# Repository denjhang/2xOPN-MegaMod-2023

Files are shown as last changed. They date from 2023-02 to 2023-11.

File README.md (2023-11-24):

# 2xOPN-MegaMod 
 New version 2xOPN expansion module, adding the latest stereo selection circuit, suitable for MegaGRRL Desktop.  

# 2023.11.25
2xOPN MegaMod v0.4 and Mixer v0.2 have passed hardware testing and all functions have been verified. The old version has many problems and is not recommended.  
## 2xOPN MegaMod v0.4 includes the following features:
1. Supports playing single OPN, double OPN, single PSG, and double PSG music. Compatible with PC9801-26K, some arcade machines, ZX-Spectrum Turbo Sound FM, Atari ST, Atari STE VGM format music.Software driver support provided by natalie.  

## 2xOPN Mixer v0.2 includes the following features:  
1. A typical dual op amp driven by a single 5V (take NE5532 as an example), it works well and sounds loud.    
2. Independent volume adjustment knob. Supports adjusting the volume of OPN and SSG, as well as the overall volume of the mixer. The volume of OPLL cannot be adjusted because the volume of OPLL itself is too small. This function is completely normal, and the volumes of each channel will not interfere with each other when adjusting the volume.  
3. SSG can be configured with stereo sound. Use three three-position toggle switches to independently control the stereo channels of each SSG. This function is completely normal and will not affect the volume of OPN and OPLL.
4. SSG stereo mixing circuit. This part is based on the ZX-Spectrum's golden ratio mixing circuit, but I modified the resistor values to provide a more stereo effect.  
5. Stereo FM mixing circuit, especially used for dual OPN music.
6. Fully configurable OPN stereo, switched using a three-position switch.

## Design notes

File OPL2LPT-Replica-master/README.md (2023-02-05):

# OPL2LPT-Replica

## Introduction
**OPL2LPT-Replica** is a re-designed, open-source simplified version of OPL2LPT circuit board with fewer components under MIT license, acting as a YM3812 FM synthesizer on LPT port, and fully ***Adlib Card*** compatible.

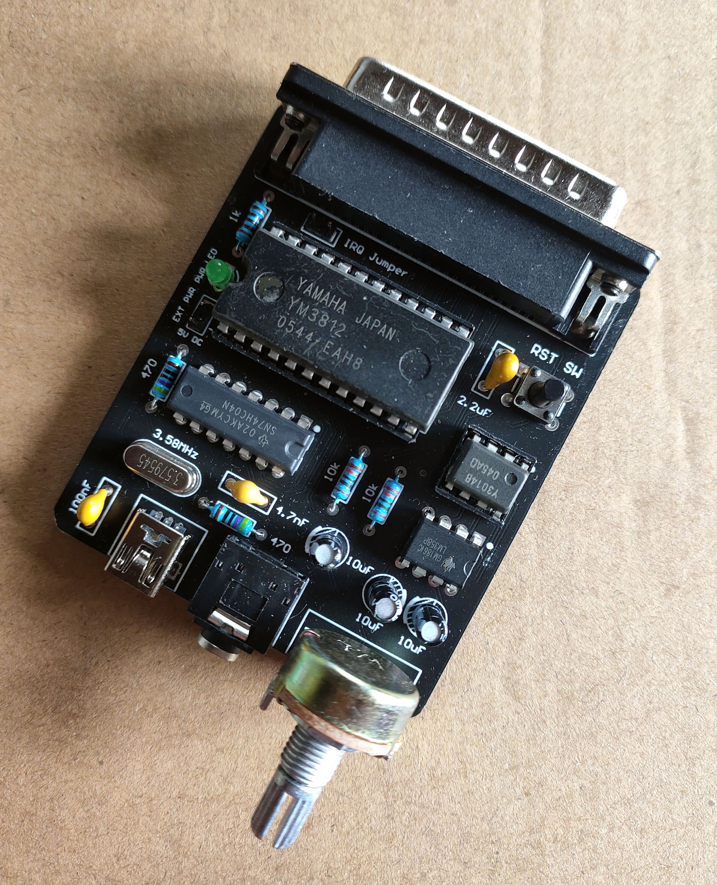
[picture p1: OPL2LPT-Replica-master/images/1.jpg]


Buy the original version of OPL2LPT and for more info: https://www.serdashop.com/OPL2LPT

## Development & Manufacture
- Please use ***Altium Designer 16*** or above to open or edit the PCB project

- Gerber files and NC drill files are already exported in `gerbers` folder, so that PCB samples can be easily manufactured

   https://www.jlc.com/ is recommended to order PCB samples in China

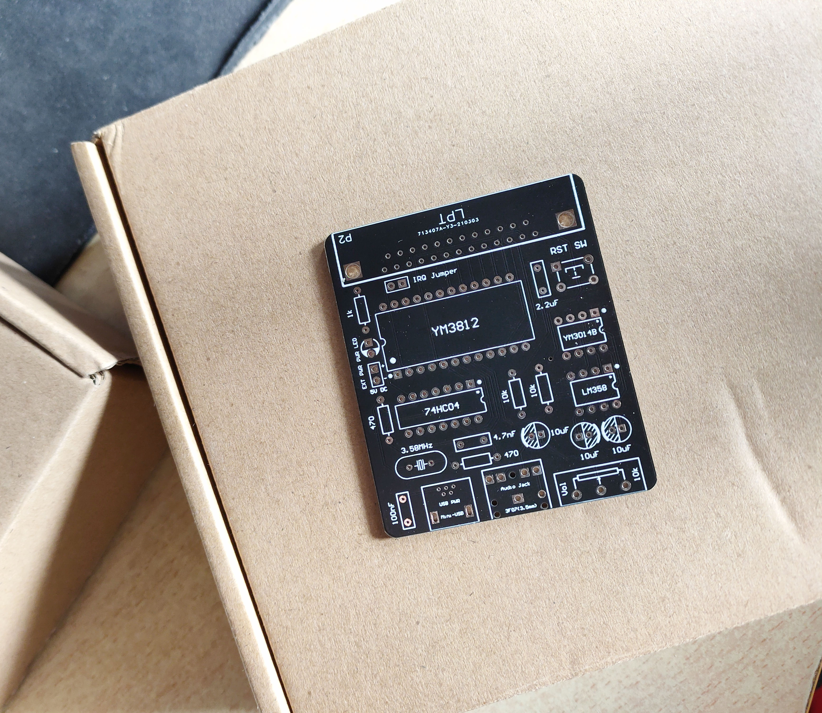
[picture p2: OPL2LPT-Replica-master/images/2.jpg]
   
## Bill of Material

| Component | Designator | Quantity | Note & Possible Sources |
| --- | --- | --- | --- |
| Leaded 100pF (101) MLCC | C1 | 1 | Mouser 594-K101J15C0GF5UH5 |
| Leaded 100nF (104) MLCC | C2 | 1 | Mouser 594-K104K15X7RF5UL2 |
| Leaded 10uF Pol. Cap. | C3, C5, C6 | 3 | Mouser 667-ECA-1EM100 |
| Leaded 2.2uF (225) MLCC | C4 | 1 | Mouser 81-RDER71H225K2M1H3A |
| Leaded 3mm Green LED | D1 | 1 | Mouser 630-HLMP-Y801-JPP00 |
| 74HC04 CMOS Inverters | IC1 | 1 | Mouser 595-CD74HC04E |
| Yamaha YM3014B DAC | IC2 | 1 | https://www.aliexpress.com/item/32611185781.html, DIP-8 socket is recommended |
| Yamaha YM3812 OPL2 | IC3 | 1 | https://www.aliexpress.com/item/32595976031.html, DIP-24 socket is recommended |
| LM358 Dual OP Amp | IC4 | 1 | Mouser 595-LM358AP |
| Leaded Mini USB Type B Connector | P1 | 1 | Mouser 571-2172034-1 |
| D-Sub 25P R/A Male Connector | P2 | 1 | Mouser 523-L717SDB25P1ACH3R |
| Header 2P 2.54mm | P3, W1 | 2 | Mouser 855-M20-9990246 |
| 3F07 3.5mm Stereo Audio Jack | P4 | 1 | https://www.aliexpress.com/i/32478957056.html |
| 1k 1/4W Resistor | R1, R2, R3 | 3 | Mouser 279-YR1B1K0CC |
| 10k WH148  Potentiometer | R4 | 1 | https://www.aliexpress.com/item/32998649900.html |
| 10k 1/4W Resistor | R5, R6 | 2 | Mouser 279-YR1B10KCC |
| TSW DIP-6\*6\*11 Key | S1 | 1 | https://www.aliexpress.com/item/32725384168.html |
| Crystal HC-49S 3.58MHz | Y1 | 1 | Mouser 449-LFXTAL032257BULK |

## Notes for Assembling & Testing
- 5V DC power is needed, either from Mini-USB port or external power pins

- Try to press **RST SW** to apply a manual reset when YM3812 behaves abnormal

- Detailed parameters for components are noted on the board's silkscreen

- Crystal must be 3.58MHz for accurate pitch of notes

- Using 74LS04 to substitute 74HC04 for the Pierce oscillator is not recommended

  **Note**: If the oscillator doesn't work, replace the two 1k ohms resistors around the 74HC04 IC with higher value resistors such as 4.7k ohms. Fine tuning for 100pF (101) MLCC capacitor around the 74HC04 may be also needed.

- Available open-source drivers for this project:
  - on MS-DOS: https://github.com/pdewacht/adlipt
    
    working fine using either method below
    
    - Using TSR  `adlipt`  for port mapping (with emm386.exe)
    - Using  `adpatch`  to patch part of DOS games
    
  - on Windows 3.1: https://github.com/andreiw/adlib21
## Update Logs
- Version 0.1(beta): First PCB for debugging
- Version 0.2(beta):
  - A smaller re-designed PCB
  - Audio quality improved
- Version 0.3(beta): Fix unconnected GND net for 3.5mm audio jack
- Version 1.0:
  - First version updated on https://github.com/
  - Fix power LED & volume control's problem
  - Use a round PCB corner for easier assembling (with a 3D-Printed case)
  - Pull-up resistors on bus are removed to improve compatibility for some old PCs
  - Use non-SMT Mini-USB port, making it easier to solder by hand
  - Add external 5V-DC power pins
- Version 1.0.1:
  - Add 3D-Printed case (with cover) and knob
  
    Thanks for **@zhblue** for your awesome *.stl models
  
  - Change directory structure for GitHub repo

- Version 1.1.0:
  - Fix clock problem caused by unsuitable resistors and capacitor for Pierce oscillator
  - Add Bill of Material and some images for this README document
  - Export PDF version for schematic and PCB documents

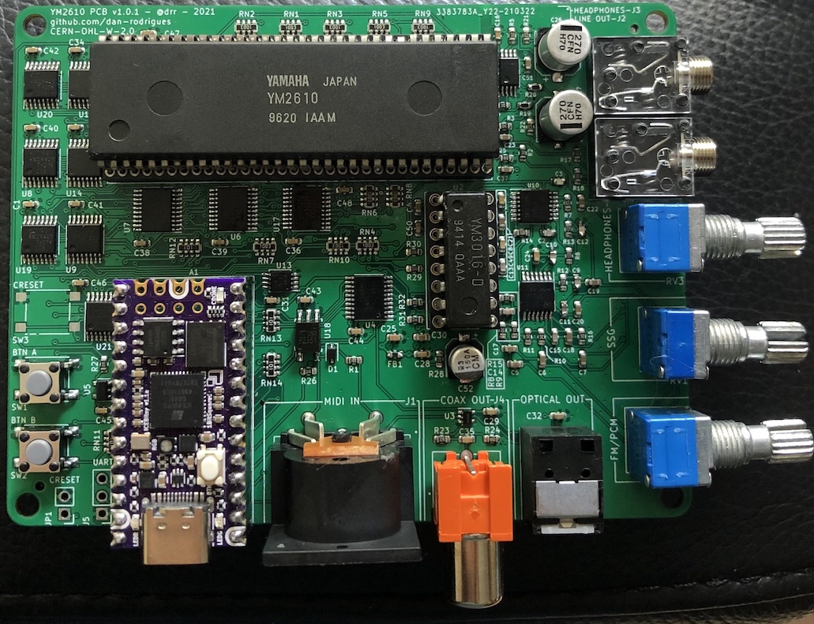
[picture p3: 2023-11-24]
参考资料/ym2610-pcb-master/ym2610-pcb-master/photo/pcb4.jpg

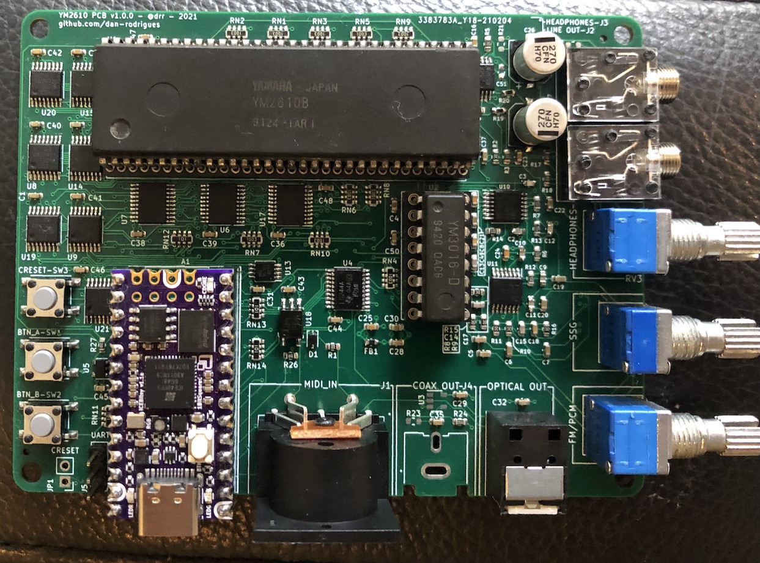
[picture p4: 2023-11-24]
参考资料/ym2610-pcb-master/ym2610-pcb-master/photo/pcb3.jpg

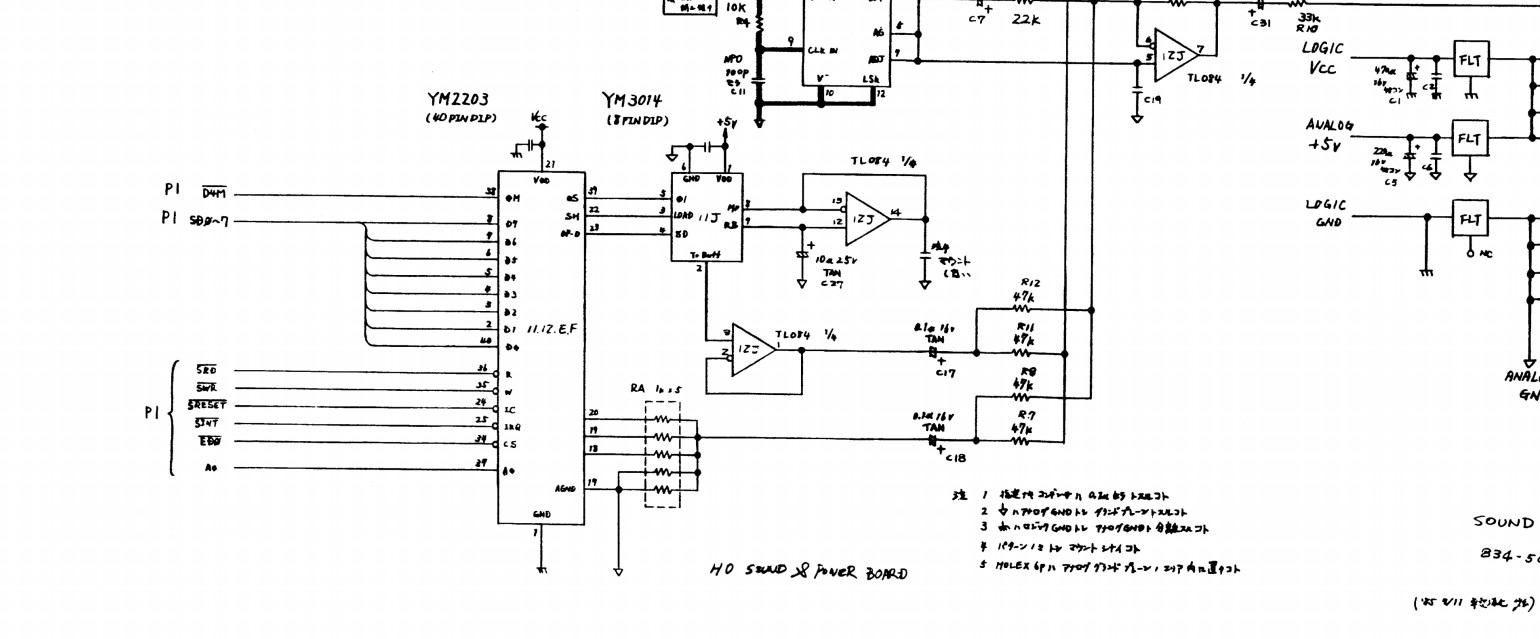
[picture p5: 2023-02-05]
截图未命名0113194031.jpeg

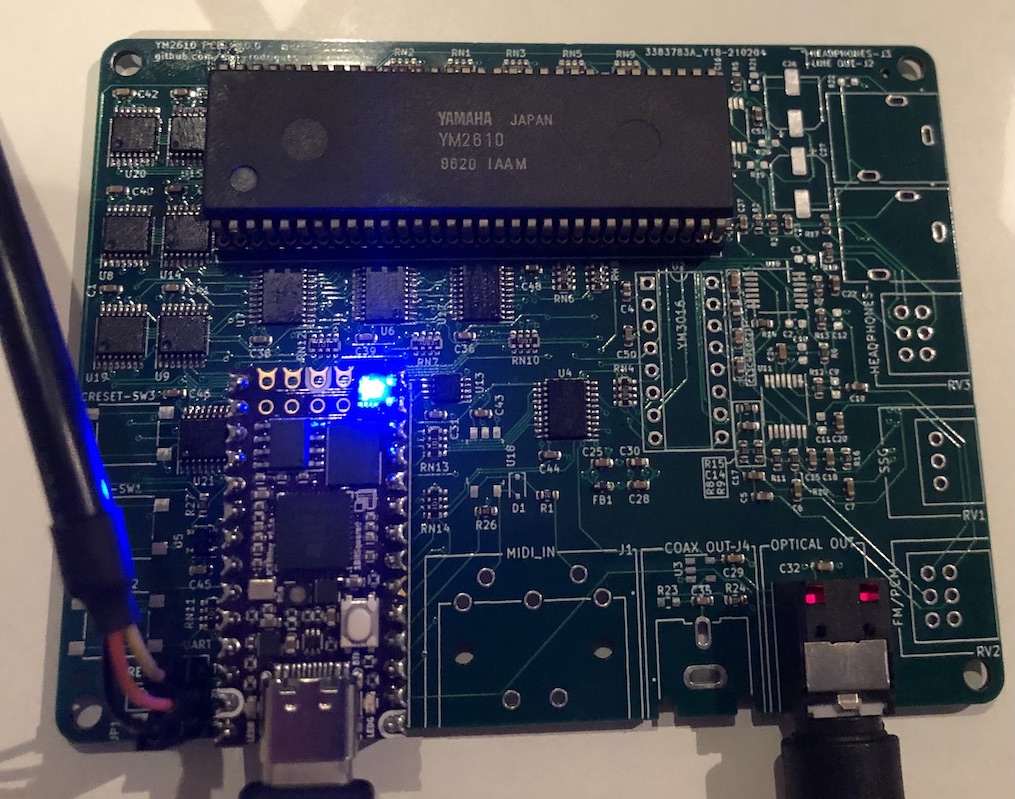
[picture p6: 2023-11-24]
参考资料/ym2610-pcb-master/ym2610-pcb-master/photo/pcb1.jpg

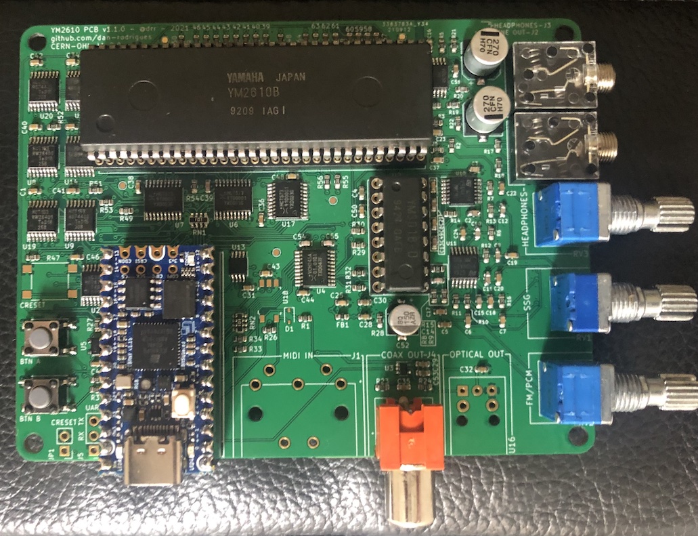
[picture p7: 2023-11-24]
参考资料/ym2610-pcb-master/ym2610-pcb-master/photo/pcb5.jpg

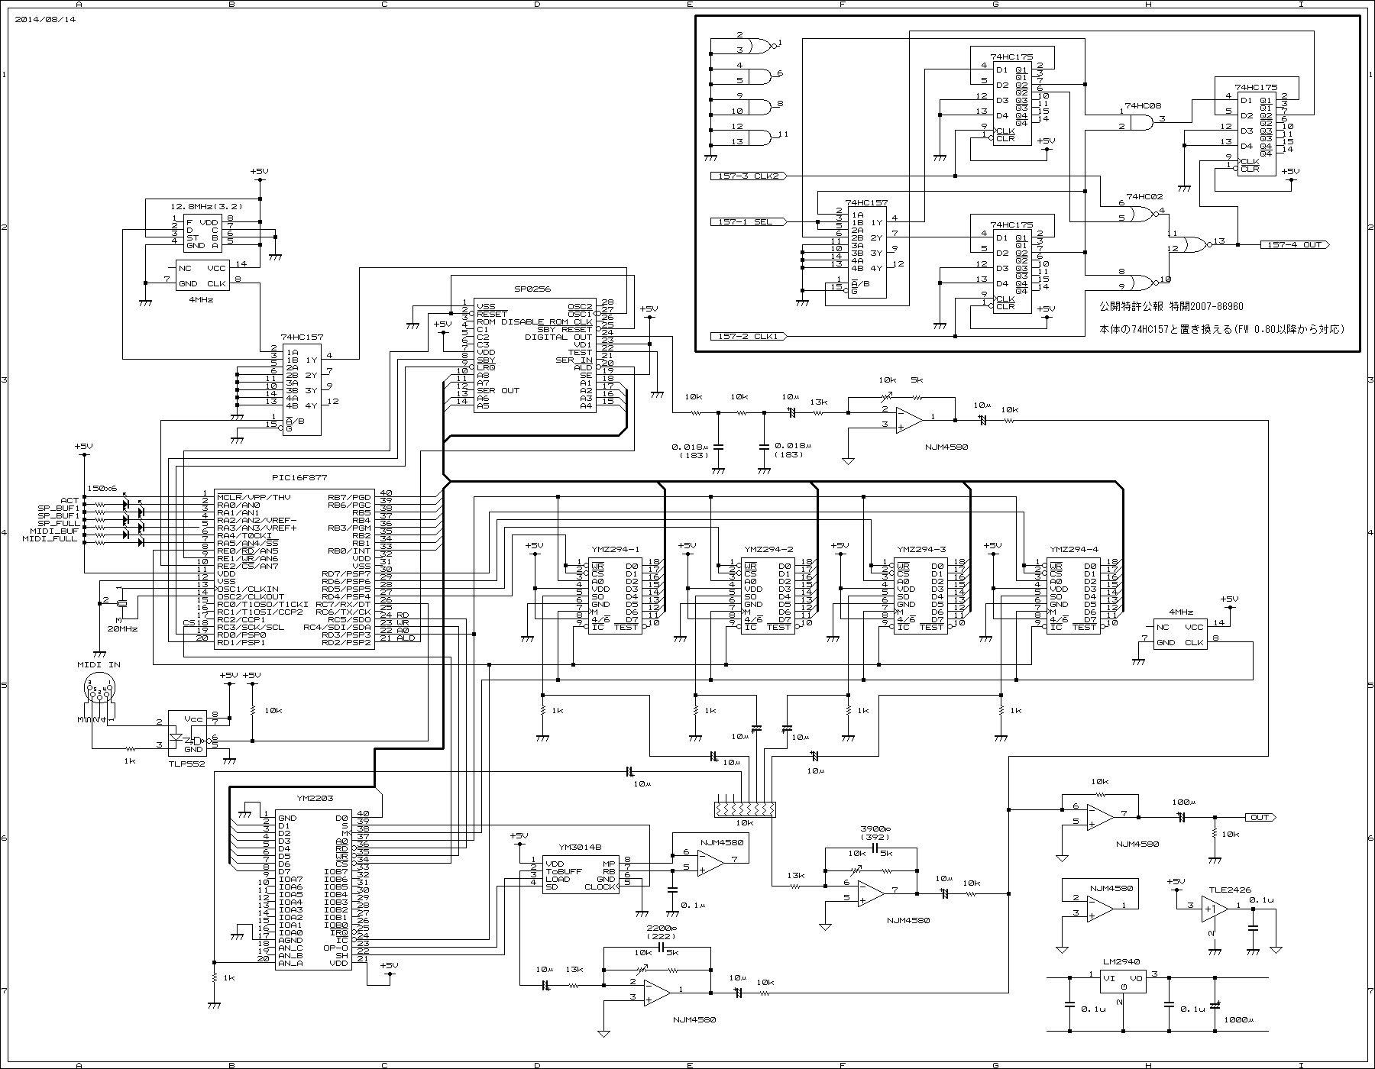
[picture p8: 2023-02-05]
schem.gif

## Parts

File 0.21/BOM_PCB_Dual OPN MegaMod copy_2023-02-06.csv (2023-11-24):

ID | Name | Designator | Footprint | Quantity | Manufacturer Part | Manufacturer | Supplier | Supplier Part | Price
1 | SS14 | D2,D1 | SMA_L4.4-W2.8-LS5.4-RD | 2 | SS14 | MDD | LCSC | C2480 | 0.0907
2 | PTC1206 0.75A/60V | FUSE1 | F1206 | 1 | PTC1206SMD1206P010TF0.1A/60V | null | LCSC | C9900017664
3 | LED0603 | LED1 | LED0603-RD | 1 | GBG-C192KRKT | GBG | LCSC | C2892154 | 0.0219
4 | LED-0603_R | LED2,LED3 | LED0603_RED | 2 | 19-217/R6C-AL1M2VY/3T | EVERLIGHT(台湾亿光) | LCSC | C72044 | 0.1041
5 | 5k | R24,R25 | R0603 | 2
6 | 3k3 | R26 | R0603 | 1
7 | NE5532-DJ | U8,U9,U10,U7 | DIP-8_L9.4-W6.4-P2.54-LS9.1-BL | 4 | NE5532P | TI | LCSC | C5326 | 3.1
8 | 10kΩ | R18,R19 | RES-ADJ-TH_RK09712200MY | 2 | RK09712200MY | ALPSALPINE(阿尔卑斯阿尔派) | LCSC | C231763 | 16.38
9 | HX SS13D07VG3-DJ | SW2,SW3,SW4,SW5,SW1,SW6,SW7,SW8 | SW-TH_SS13D07VG4 | 8 | HX SS13D07VG3 | hanxia(韩下) | LCSC | C5149830 | 0.1824
10 | YM2203C | U1,U4 | DIP40 | 2
11 | YM3014 | U3,U6 | DIP8 | 2
12 | MegaGRRL IC-DCSG | U5 | DIP-16_L20.4-W5.8-P2.54-LS7.6-BL | 1 | SN76489AN | Texas Instruments
13 | 5.8*5.8自锁开关 | S1,S2 | SW-TH_6P-L5.8-W5.8-P2.00-LS4.5-TR | 2 | Self-locking switch 5.8ZWhite and white260G | ReliaPro | LCSC | C56857 | 0.504
14 | PJ-307C | J1 | AUDIO-TH_PJ307C | 1 | PJ-307C | BOOMELE | LCSC | C16684 | 0.3127
15 | MegaGRRL IC-FM | U2 | DIP-24_L32.0-W13.8-P2.54-LS15.6-BL | 1 | YM2612 | YAMAHA |  | C707077 | 11.24
16 | 10u | C5,C6,C7,C17,C18,C13,C14,C8 | C0805 | 8
17 | 4.7u | C15,C16 | C0805 | 2
18 | 100Ω | L1 | L0603 | 1 | CBW160808U102T | FH | LCSC | C50069 | 0.0321
19 | 0.1u | C1,C2,C3,C4,C11,C12 | C0603 | 6
20 | 1n | C9,C10 | C0603 | 2
21 | 1k | R1,R8,R11,R12,R13,R14,R17,R22,R23 | R0603 | 9
22 | 470r | R2,R3,R4,R5,R6,R7 | R0603 | 6
23 | 1k6 | R9,R10,R15,R16 | R0603 | 4
24 | 10k | R20,R21 | R0603 | 2

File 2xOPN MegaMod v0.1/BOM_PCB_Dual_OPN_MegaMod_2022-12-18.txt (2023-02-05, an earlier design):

ID	Name	Designator	Footprint	Quantity	Manufacturer Part	Manufacturer	Supplier	Supplier Part	Price
"1"	"SS14"	"D1"	"SMA_L4.4-W2.8-LS5.4-RD"	"1"	"SS14"	"MDD"	"LCSC"	"C2480"	"0.0907"
"2"	"100Ω"	"L1"	"L0603"	"1"	"CBW160808U102T"	"FH"	"LCSC"	"C50069"	"0.0321"
"3"	"1k"	"R1,R5,R6,R7,R11,R12,R13,R19,R20,R26,R27"	"R0603"	"11"	""	""	""	""	""
"4"	"3.6k"	"R17,R18,R24,R25"	"R0603"	"4"	""	""	""	""	""
"5"	"10k"	"R2,R3,R4,R8,R9,R10,R16,R23"	"R0603"	"8"	""	""	""	""	""
"6"	"3.3k"	"R14,R21"	"R0603"	"2"	""	""	""	""	""
"7"	"5.6k"	"R15,R22"	"R0603"	"2"	""	""	""	""	""
"8"	"0.1u"	"C1,C2,C3,C4,C7,C10,C12,C16,C19,C22"	"C0603"	"10"	""	""	""	""	""
"9"	"4.7u"	"C6,C9,C15,C18"	"C0603"	"4"	""	""	""	""	""
"10"	"10n"	"C8,C17"	"C0603"	"2"	""	""	""	""	""
"11"	"YM3014"	"U5,U6"	"DIP8"	"2"	""	""	""	""	""
"12"	"4.7uF"	"C5,C14,C23,C24"	"CAP-TH_BD6.3-P2.50-D1.0-FD"	"4"	"电解电容25V 47uF"	"ValuePro"	"LCSC"	"C45704"	"0.1937"
"13"	"10uF"	"C11,C21"	"CAP-TH_BD4.0-P1.50-D0.8-FD"	"2"	"47uF 10V 4*5"	"ValuePro"	"LCSC"	"C43312"	"0.077"
"14"	"10uF"	"C13,C20"	"CAP-TH_BD6.3-P2.50-D1.0-FD"	"2"	"电解电容25V 47uF"	"ValuePro"	"LCSC"	"C45704"	"0.1937"
"15"	"PJ-307C"	"J1"	"AUDIO-TH_PJ307C"	"1"	"PJ-307C"	"BOOMELE"	"LCSC"	"C16684"	"0.2836"
"16"	"YM2203C"	"U4,U3"	"DIP40"	"2"	""	""	""	""	""
"17"	"SA5532AP"	"U7,U8,U9,U10"	"DIP8"	"4"	""	""	""	""	""
"18"	"Header-Male-2.54_1x3"	"H4,H6,H7,H9,H1,H2"	"HDR-TH_3P-P2.54-V-M-1"	"6"	"Header2.54mm 1*3P"	"BOOMELE"	"LCSC"	"C49257"	"0.0872"
"19"	"X6511WV-02H-C30D60"	"H3,H5,H8"	"HDR-TH_2P-P2.54-V-M"	"3"	"X6511WV-02H-C30D60"	"XKB Connectivity"	"LCSC"	"C706874"	"0.2046"
"20"	"MegaGRRL IC-DCSG"	"U1"	"DIP-16_L20.4-W5.8-P2.54-LS7.6-BL"	"1"	"SN76489AN"	"Texas Instruments"	""	""	""
"21"	"MegaGRRL IC-FM"	"U2"	"DIP-24_L32.0-W13.8-P2.54-LS15.6-BL"	"1"	"YM2612"	"YAMAHA"	""	"C707077"	"12.04"

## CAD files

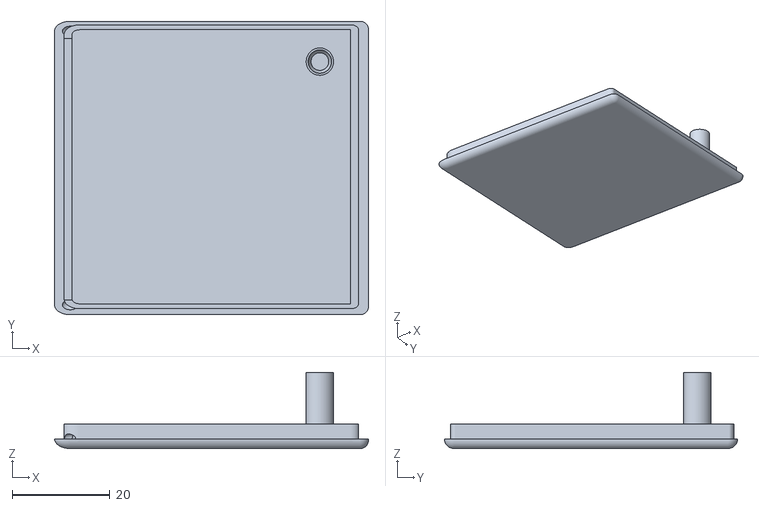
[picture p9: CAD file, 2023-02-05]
OPL2LPT-Replica-master/models/opl2cover.stl
64.2 x 60.0 x 15.6

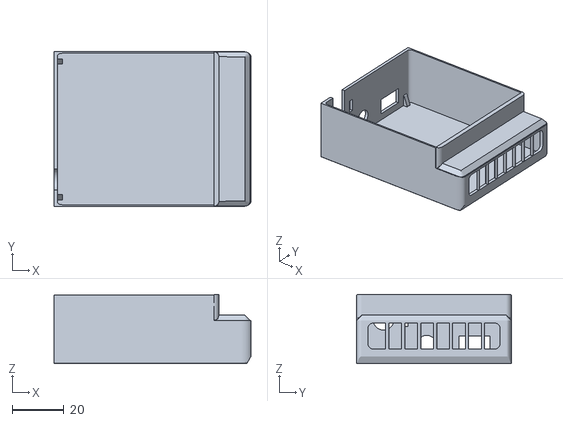
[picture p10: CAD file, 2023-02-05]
OPL2LPT-Replica-master/models/opl2box.stl
76.1 x 60.0 x 26.7

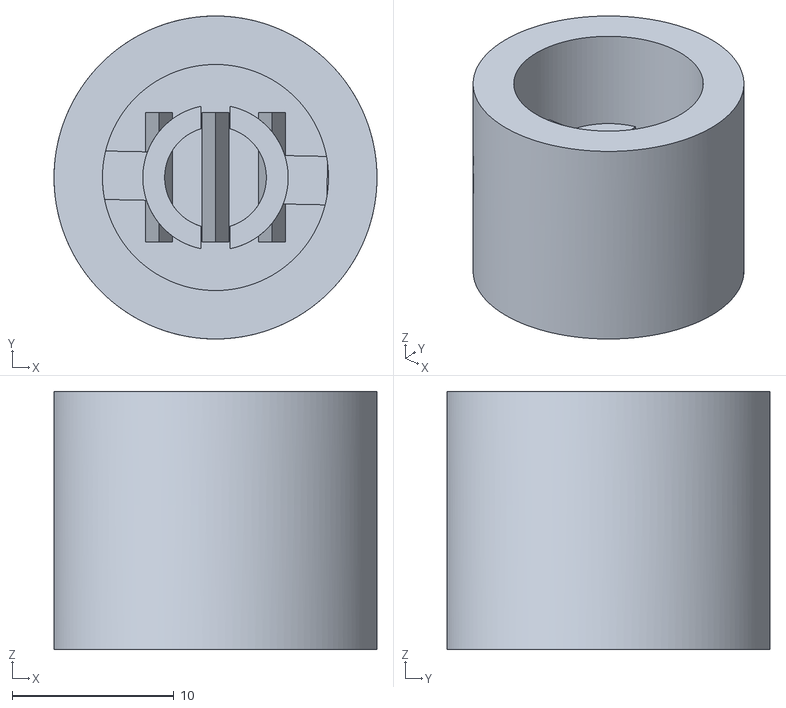
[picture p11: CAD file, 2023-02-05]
OPL2LPT-Replica-master/models/opl2knob.stl
20.0 x 20.0 x 16.0

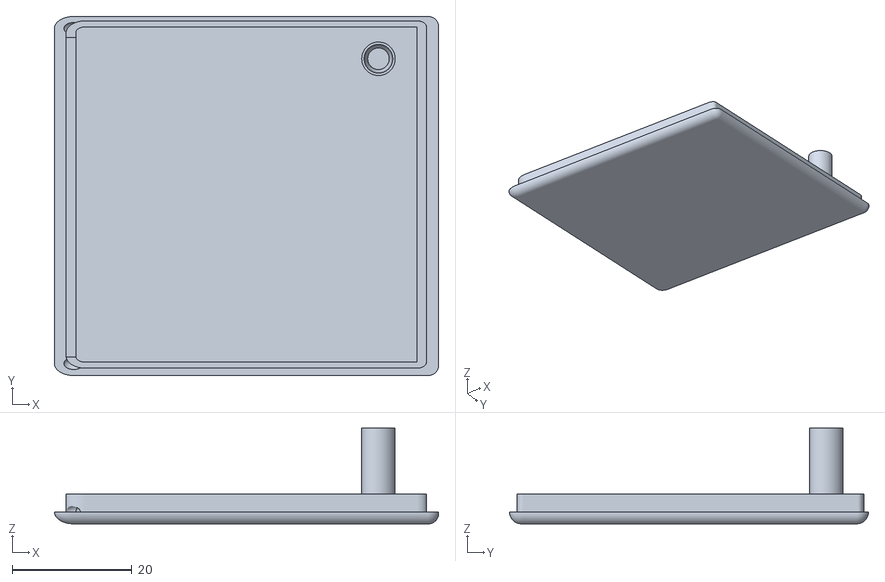
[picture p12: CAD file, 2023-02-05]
OPL2LPT-Replica-master/models/opl2coverb.stl
64.2 x 60.0 x 16.0

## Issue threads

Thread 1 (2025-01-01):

L1 / L2 are inductors or resistors?

OlivierGrimard, 2025-01-01:
Hi @denjhang,
I’m not an expert in electronics. Could you clarify if L1/L2 are inductors or resistors?
Is it possible that the value labeled as 100Ω should actually be 100nH?

Thank you

OlivierGrimard, 2025-01-04:
The answer is inductors 100nH.

Closed 2025-01-04.

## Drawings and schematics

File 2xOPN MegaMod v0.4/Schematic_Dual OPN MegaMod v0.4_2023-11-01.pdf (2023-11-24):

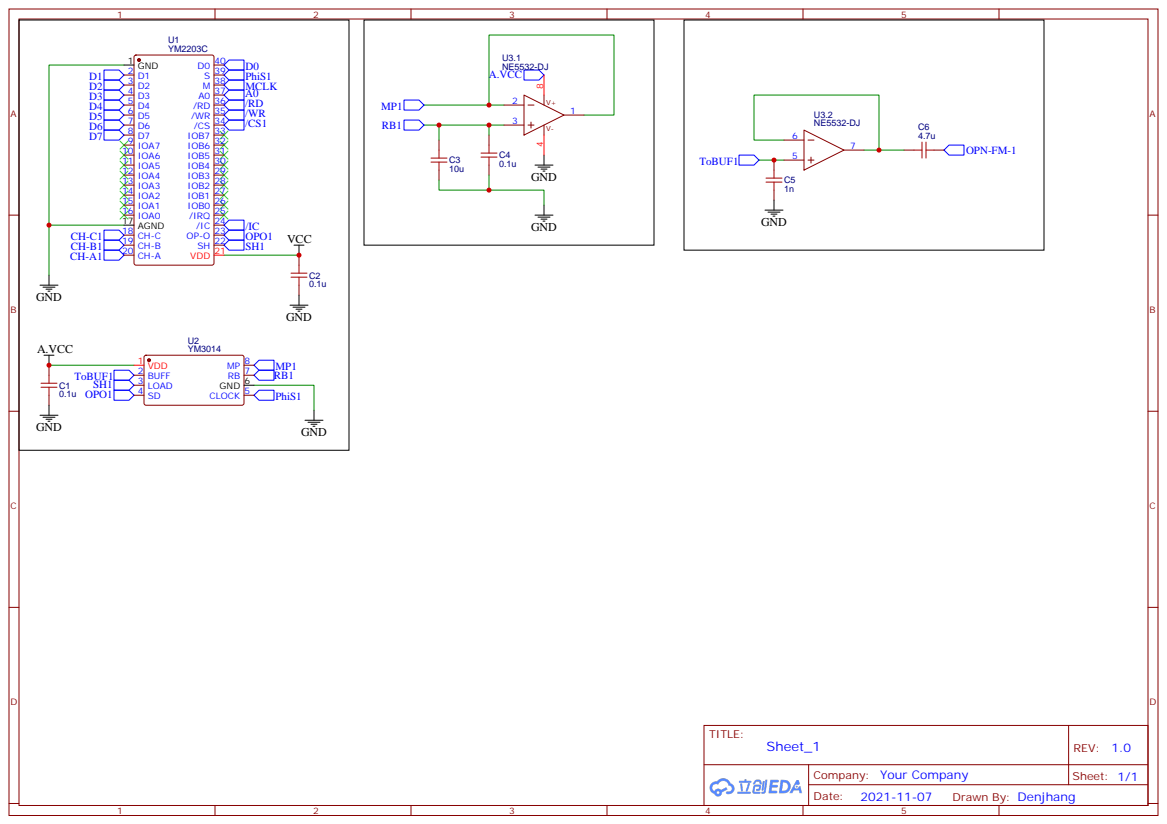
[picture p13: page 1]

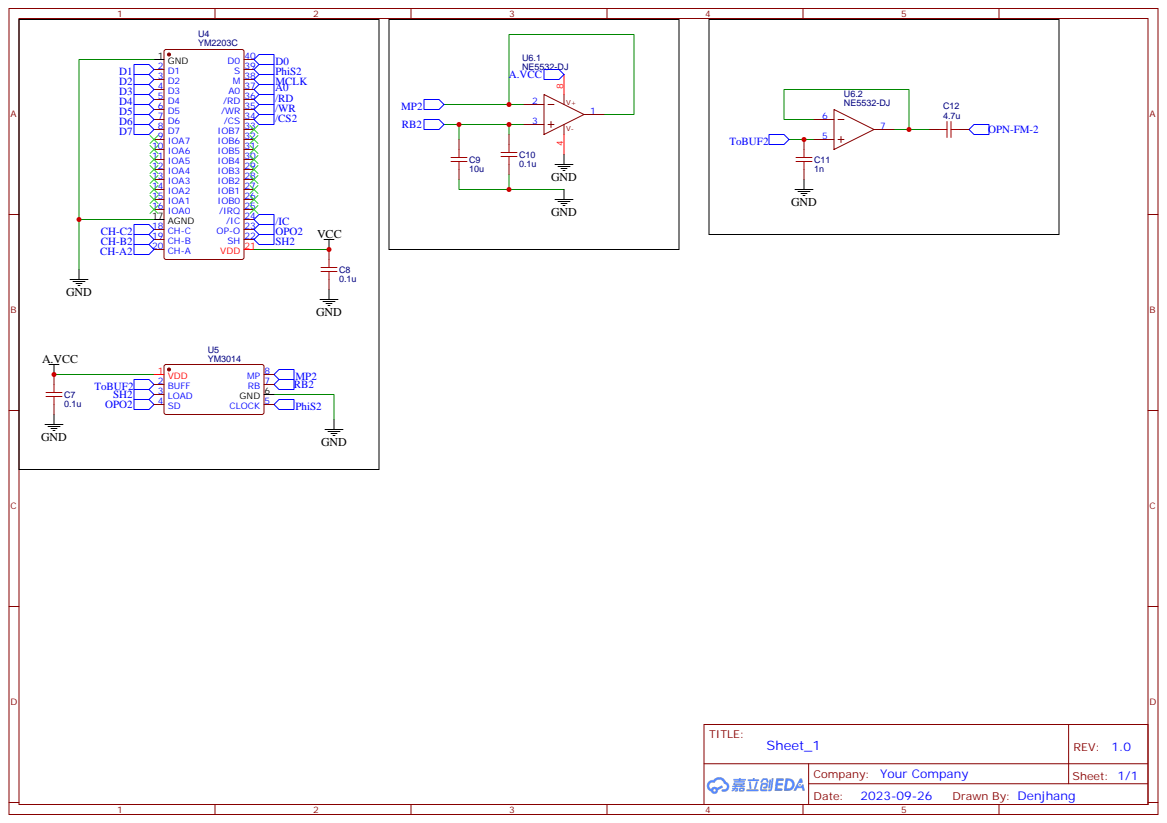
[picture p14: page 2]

## 间距53.975MM

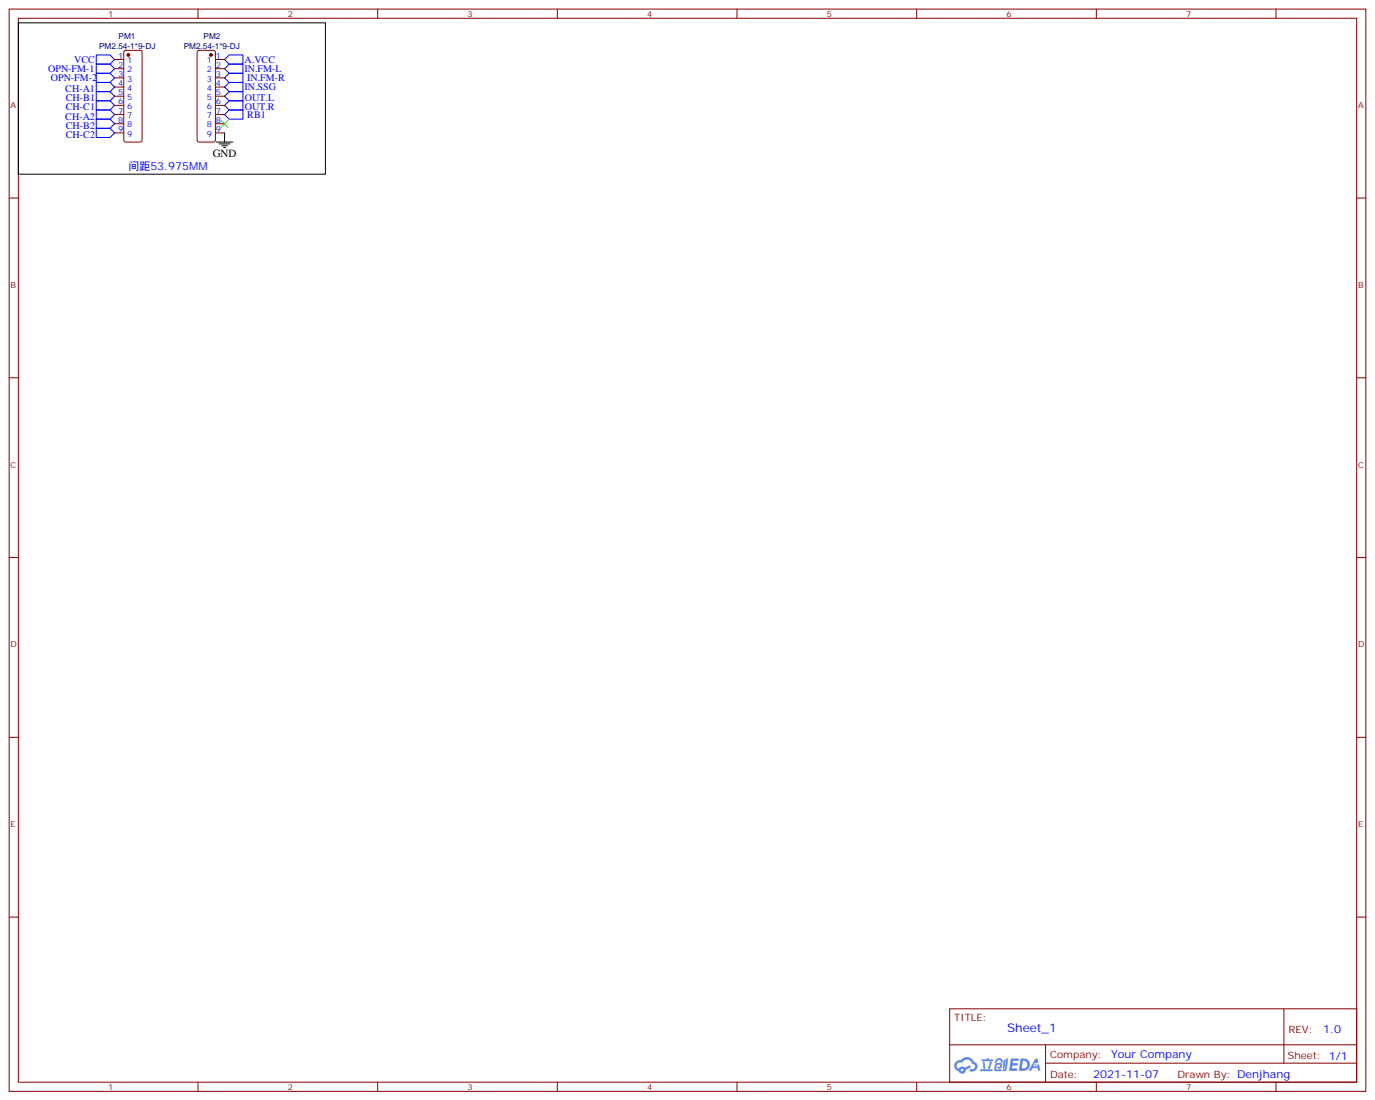
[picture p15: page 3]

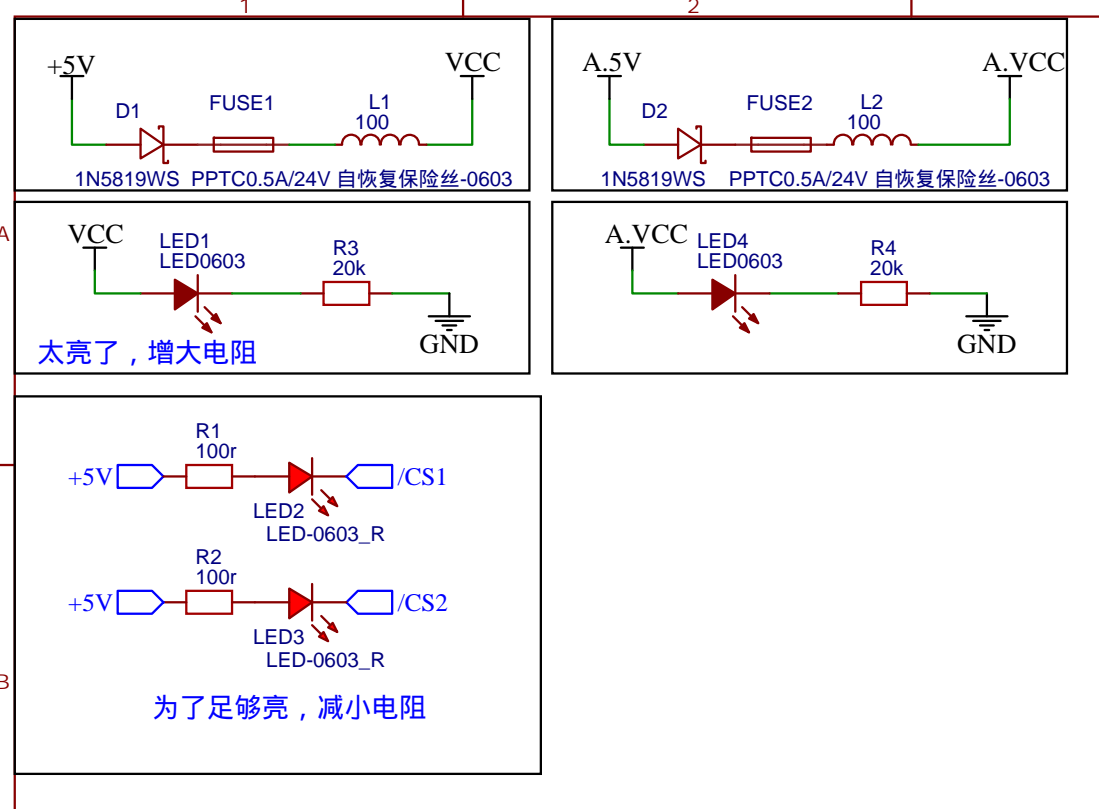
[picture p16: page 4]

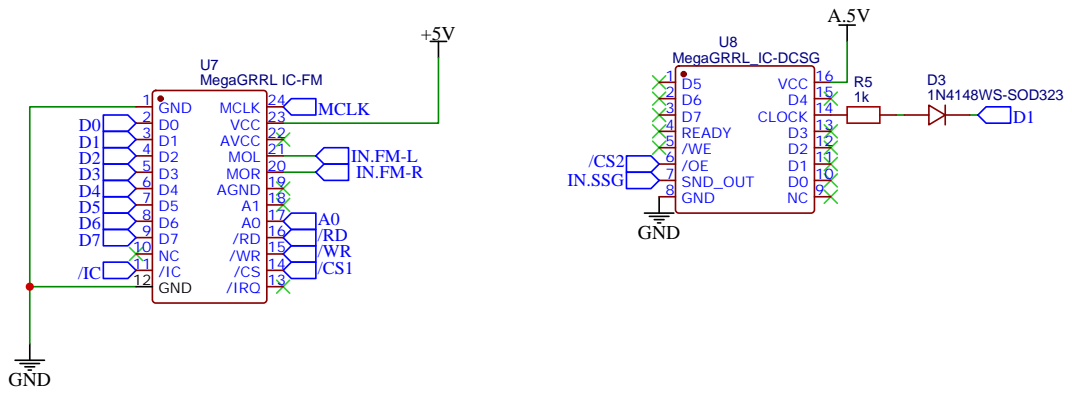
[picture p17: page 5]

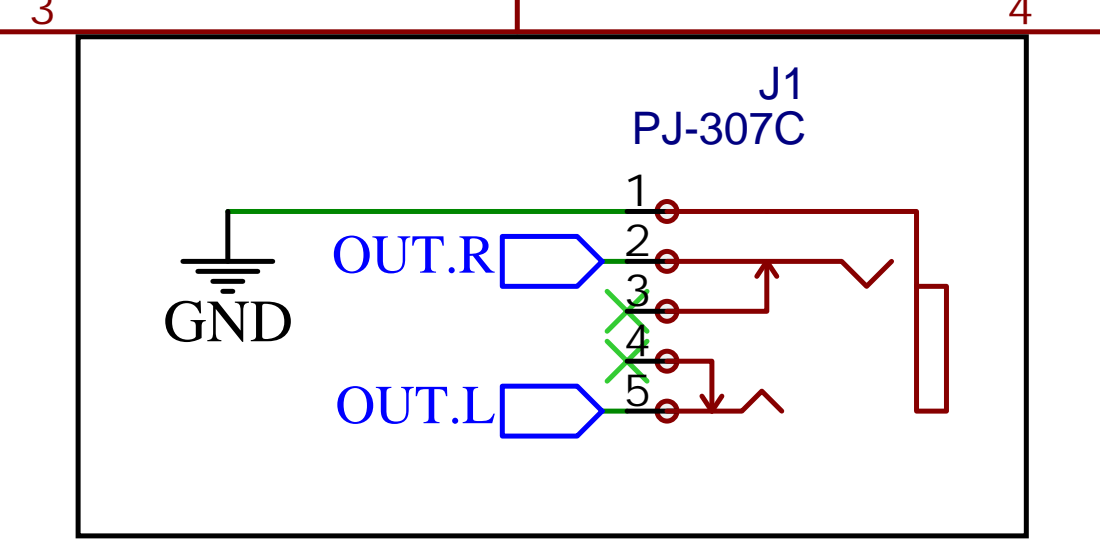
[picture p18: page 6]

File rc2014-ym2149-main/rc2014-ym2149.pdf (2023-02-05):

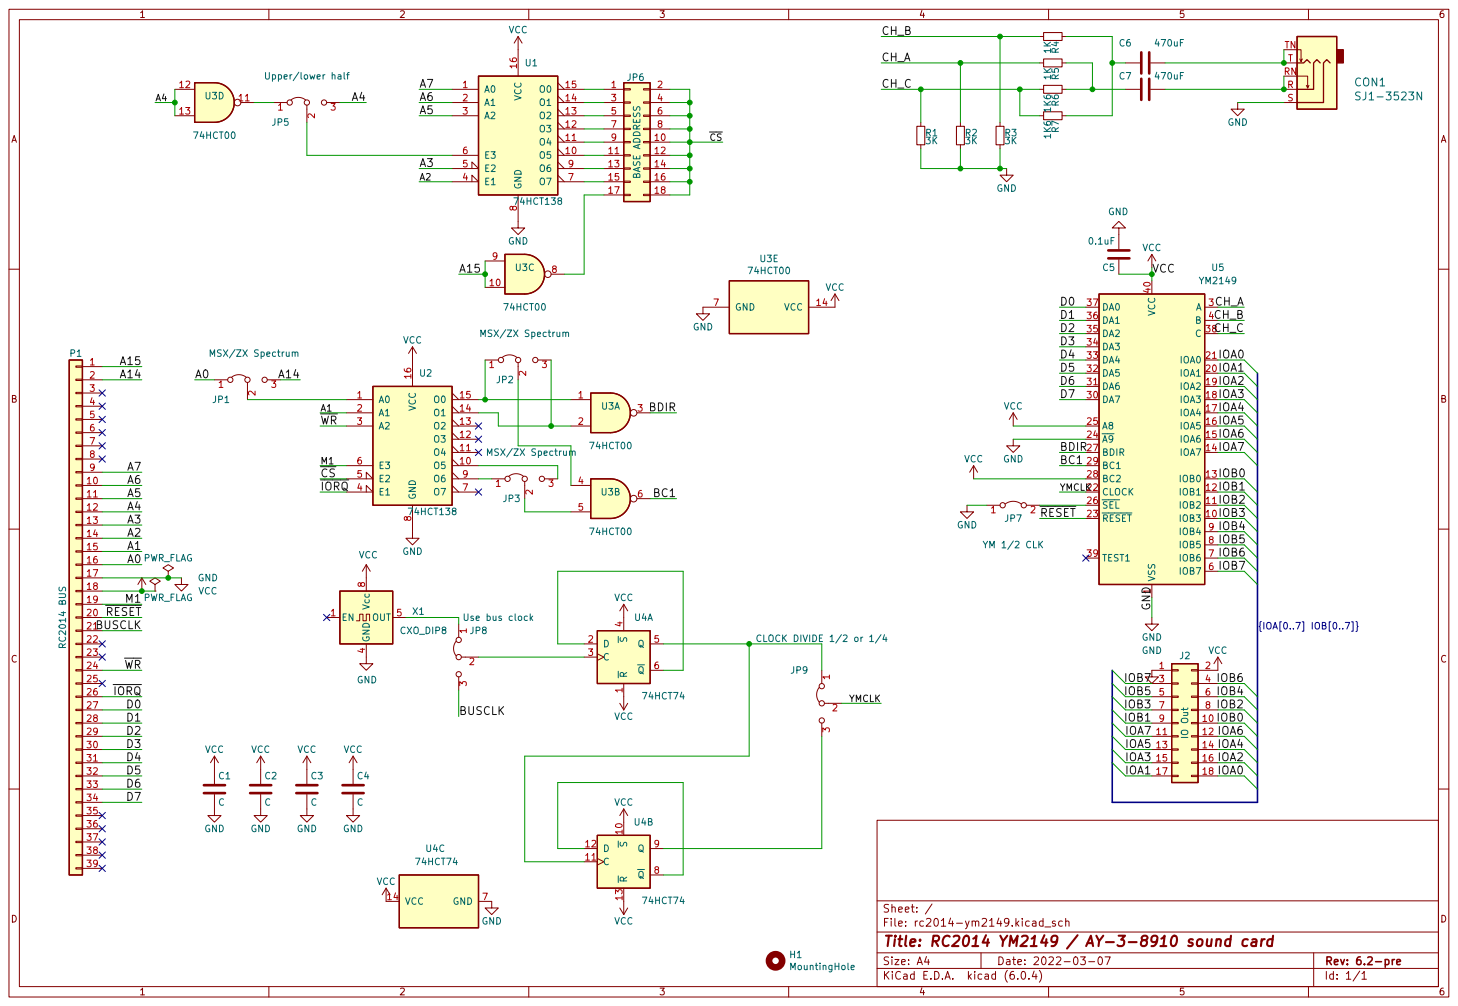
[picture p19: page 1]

13 | 14
15 | 16
17 | 18

File: rc2014-ym2149.kicad_sch Sheet: /
Id: 1/1 Title: RC2014 YM2149 / AY-3-8910 sound card

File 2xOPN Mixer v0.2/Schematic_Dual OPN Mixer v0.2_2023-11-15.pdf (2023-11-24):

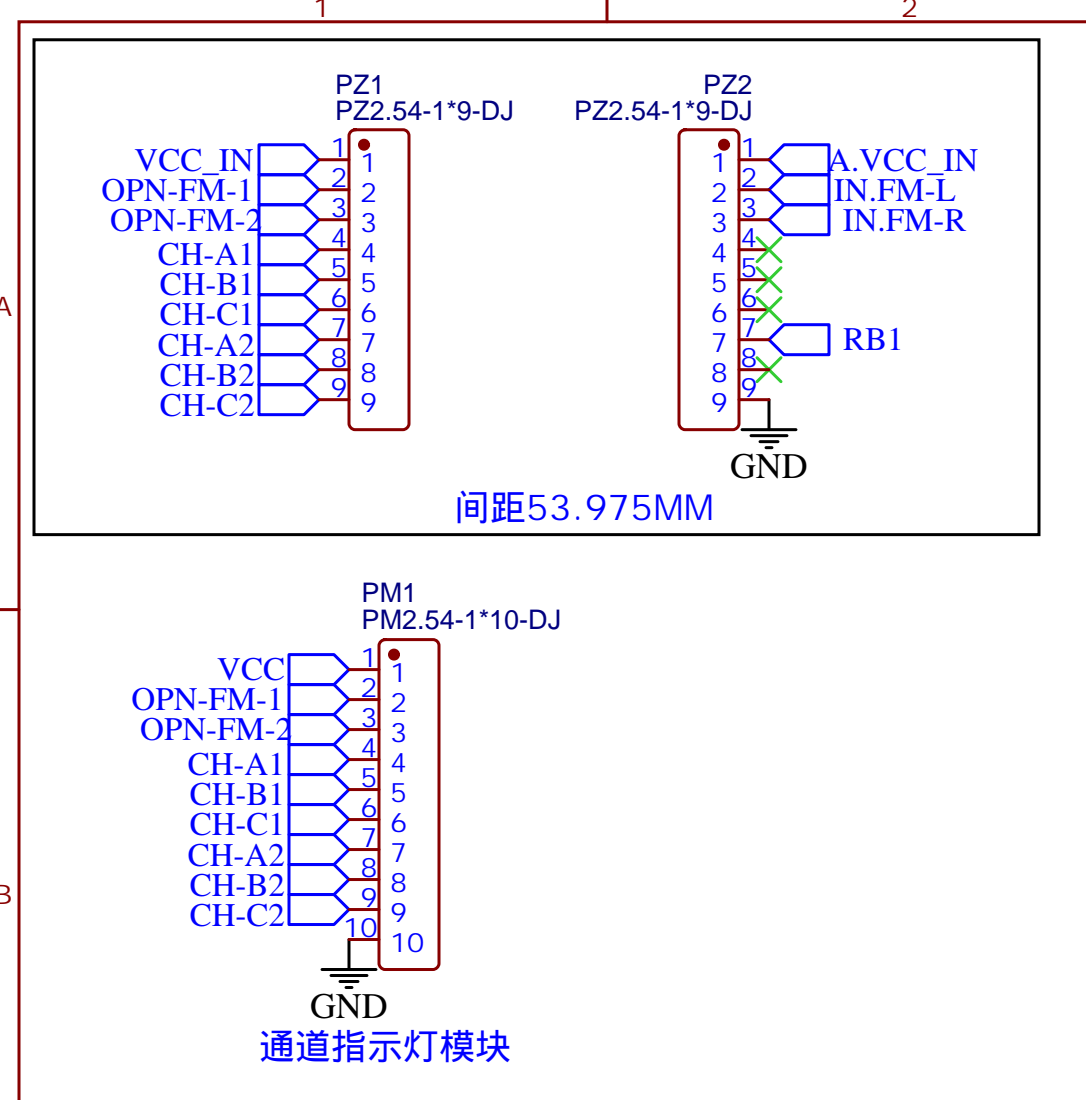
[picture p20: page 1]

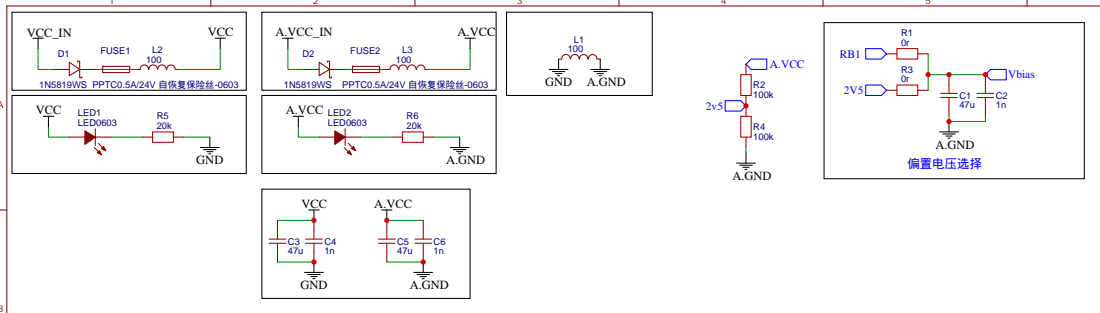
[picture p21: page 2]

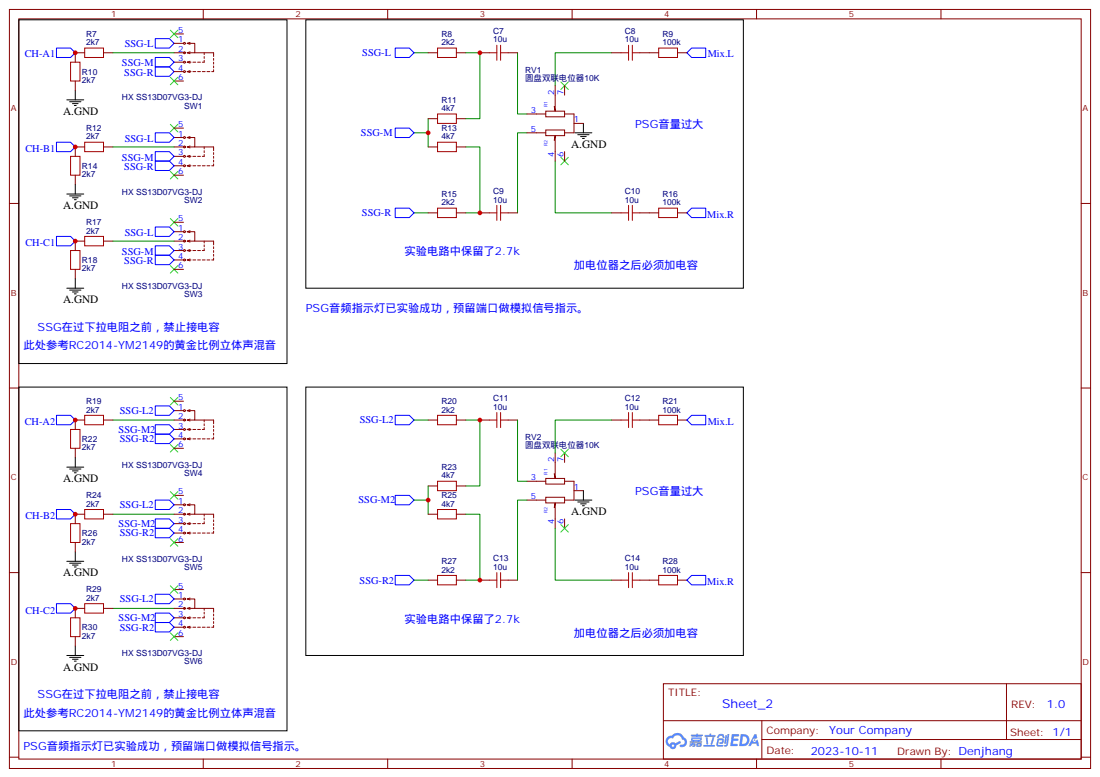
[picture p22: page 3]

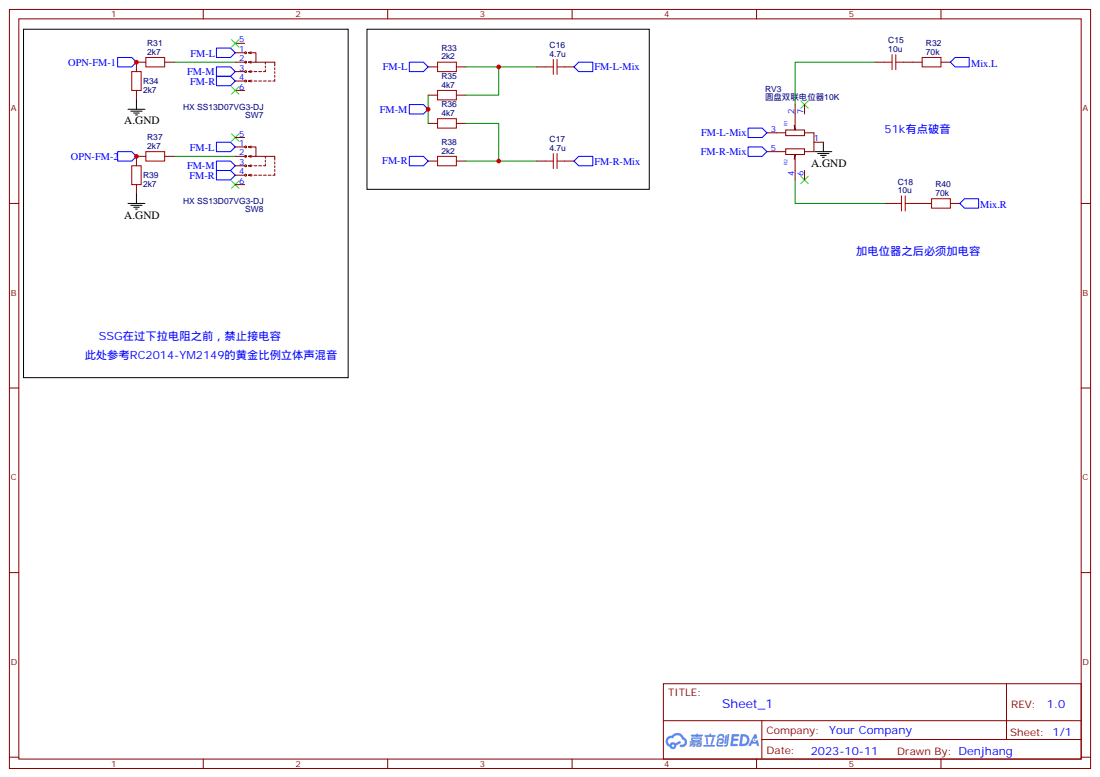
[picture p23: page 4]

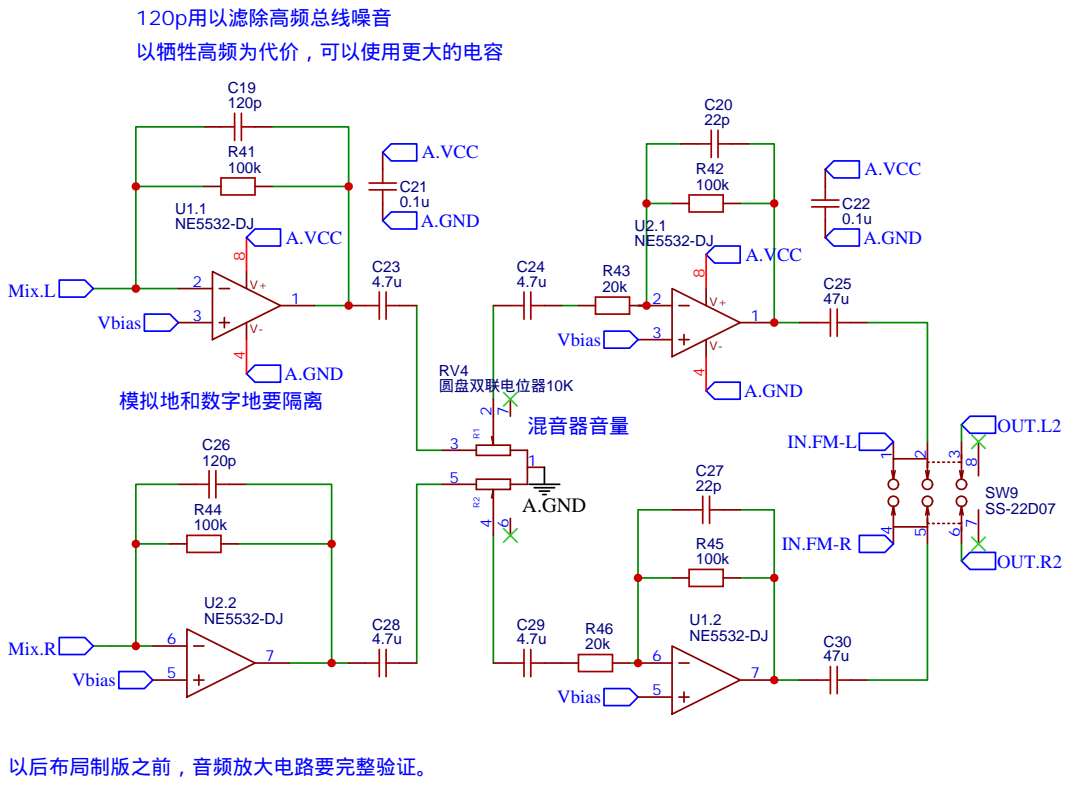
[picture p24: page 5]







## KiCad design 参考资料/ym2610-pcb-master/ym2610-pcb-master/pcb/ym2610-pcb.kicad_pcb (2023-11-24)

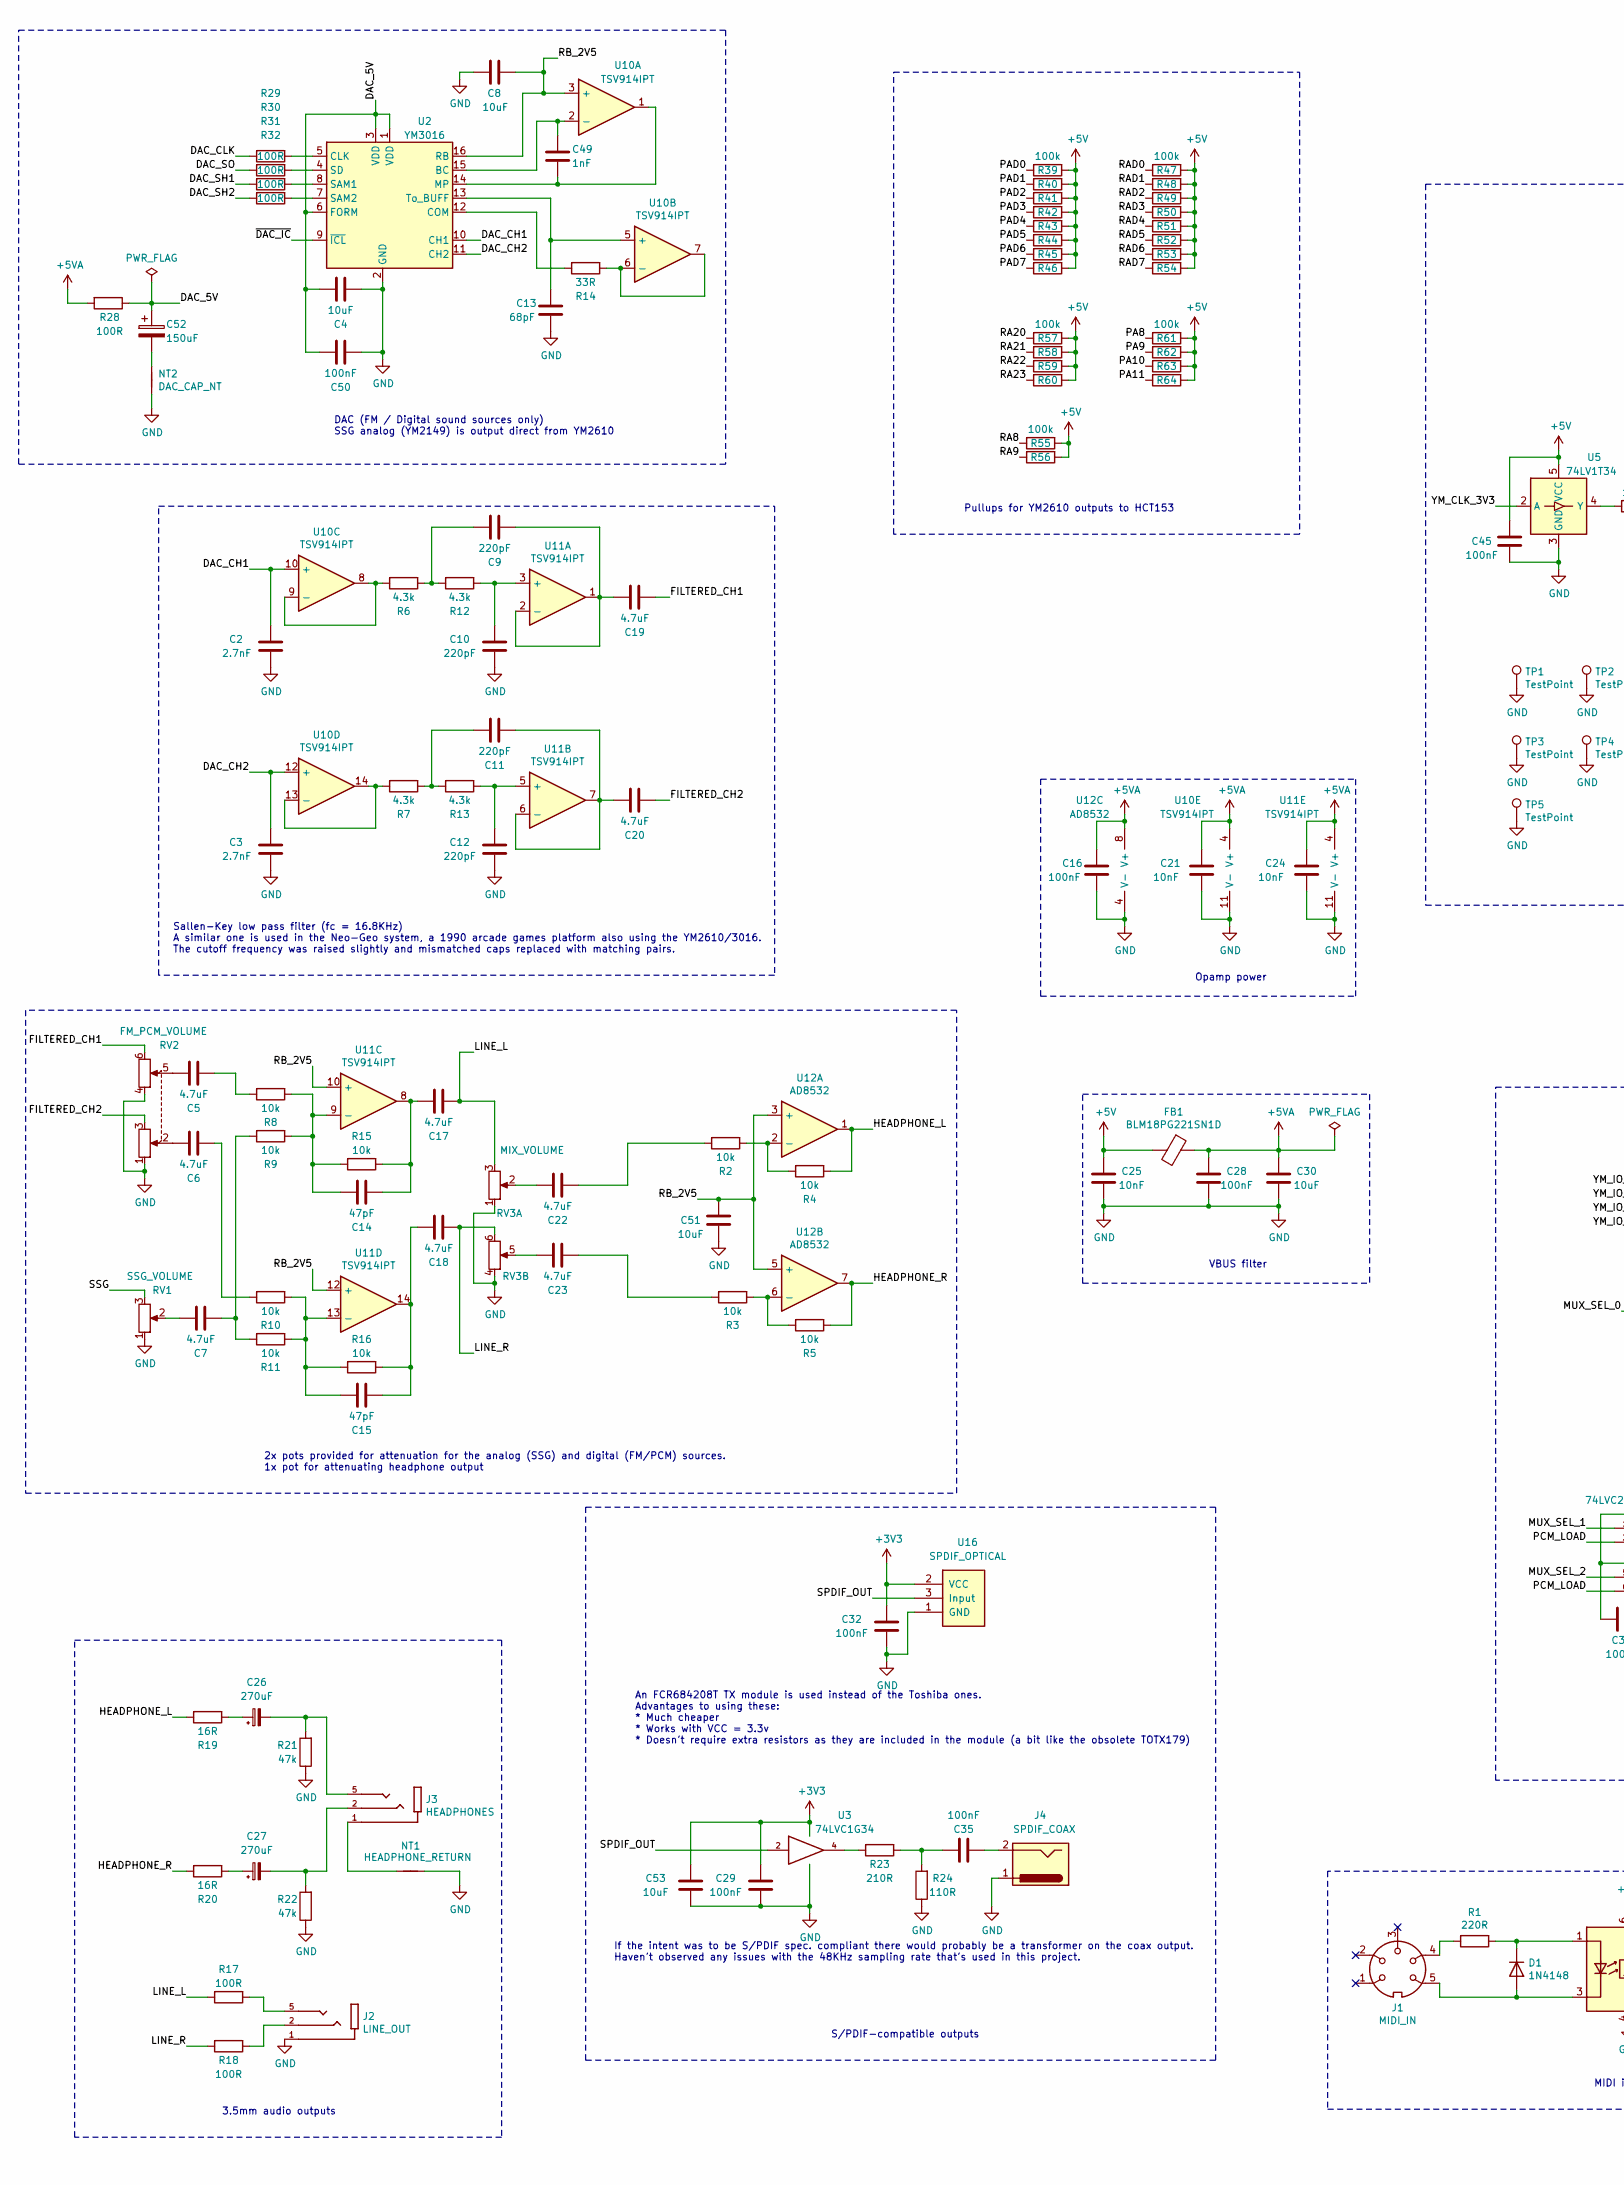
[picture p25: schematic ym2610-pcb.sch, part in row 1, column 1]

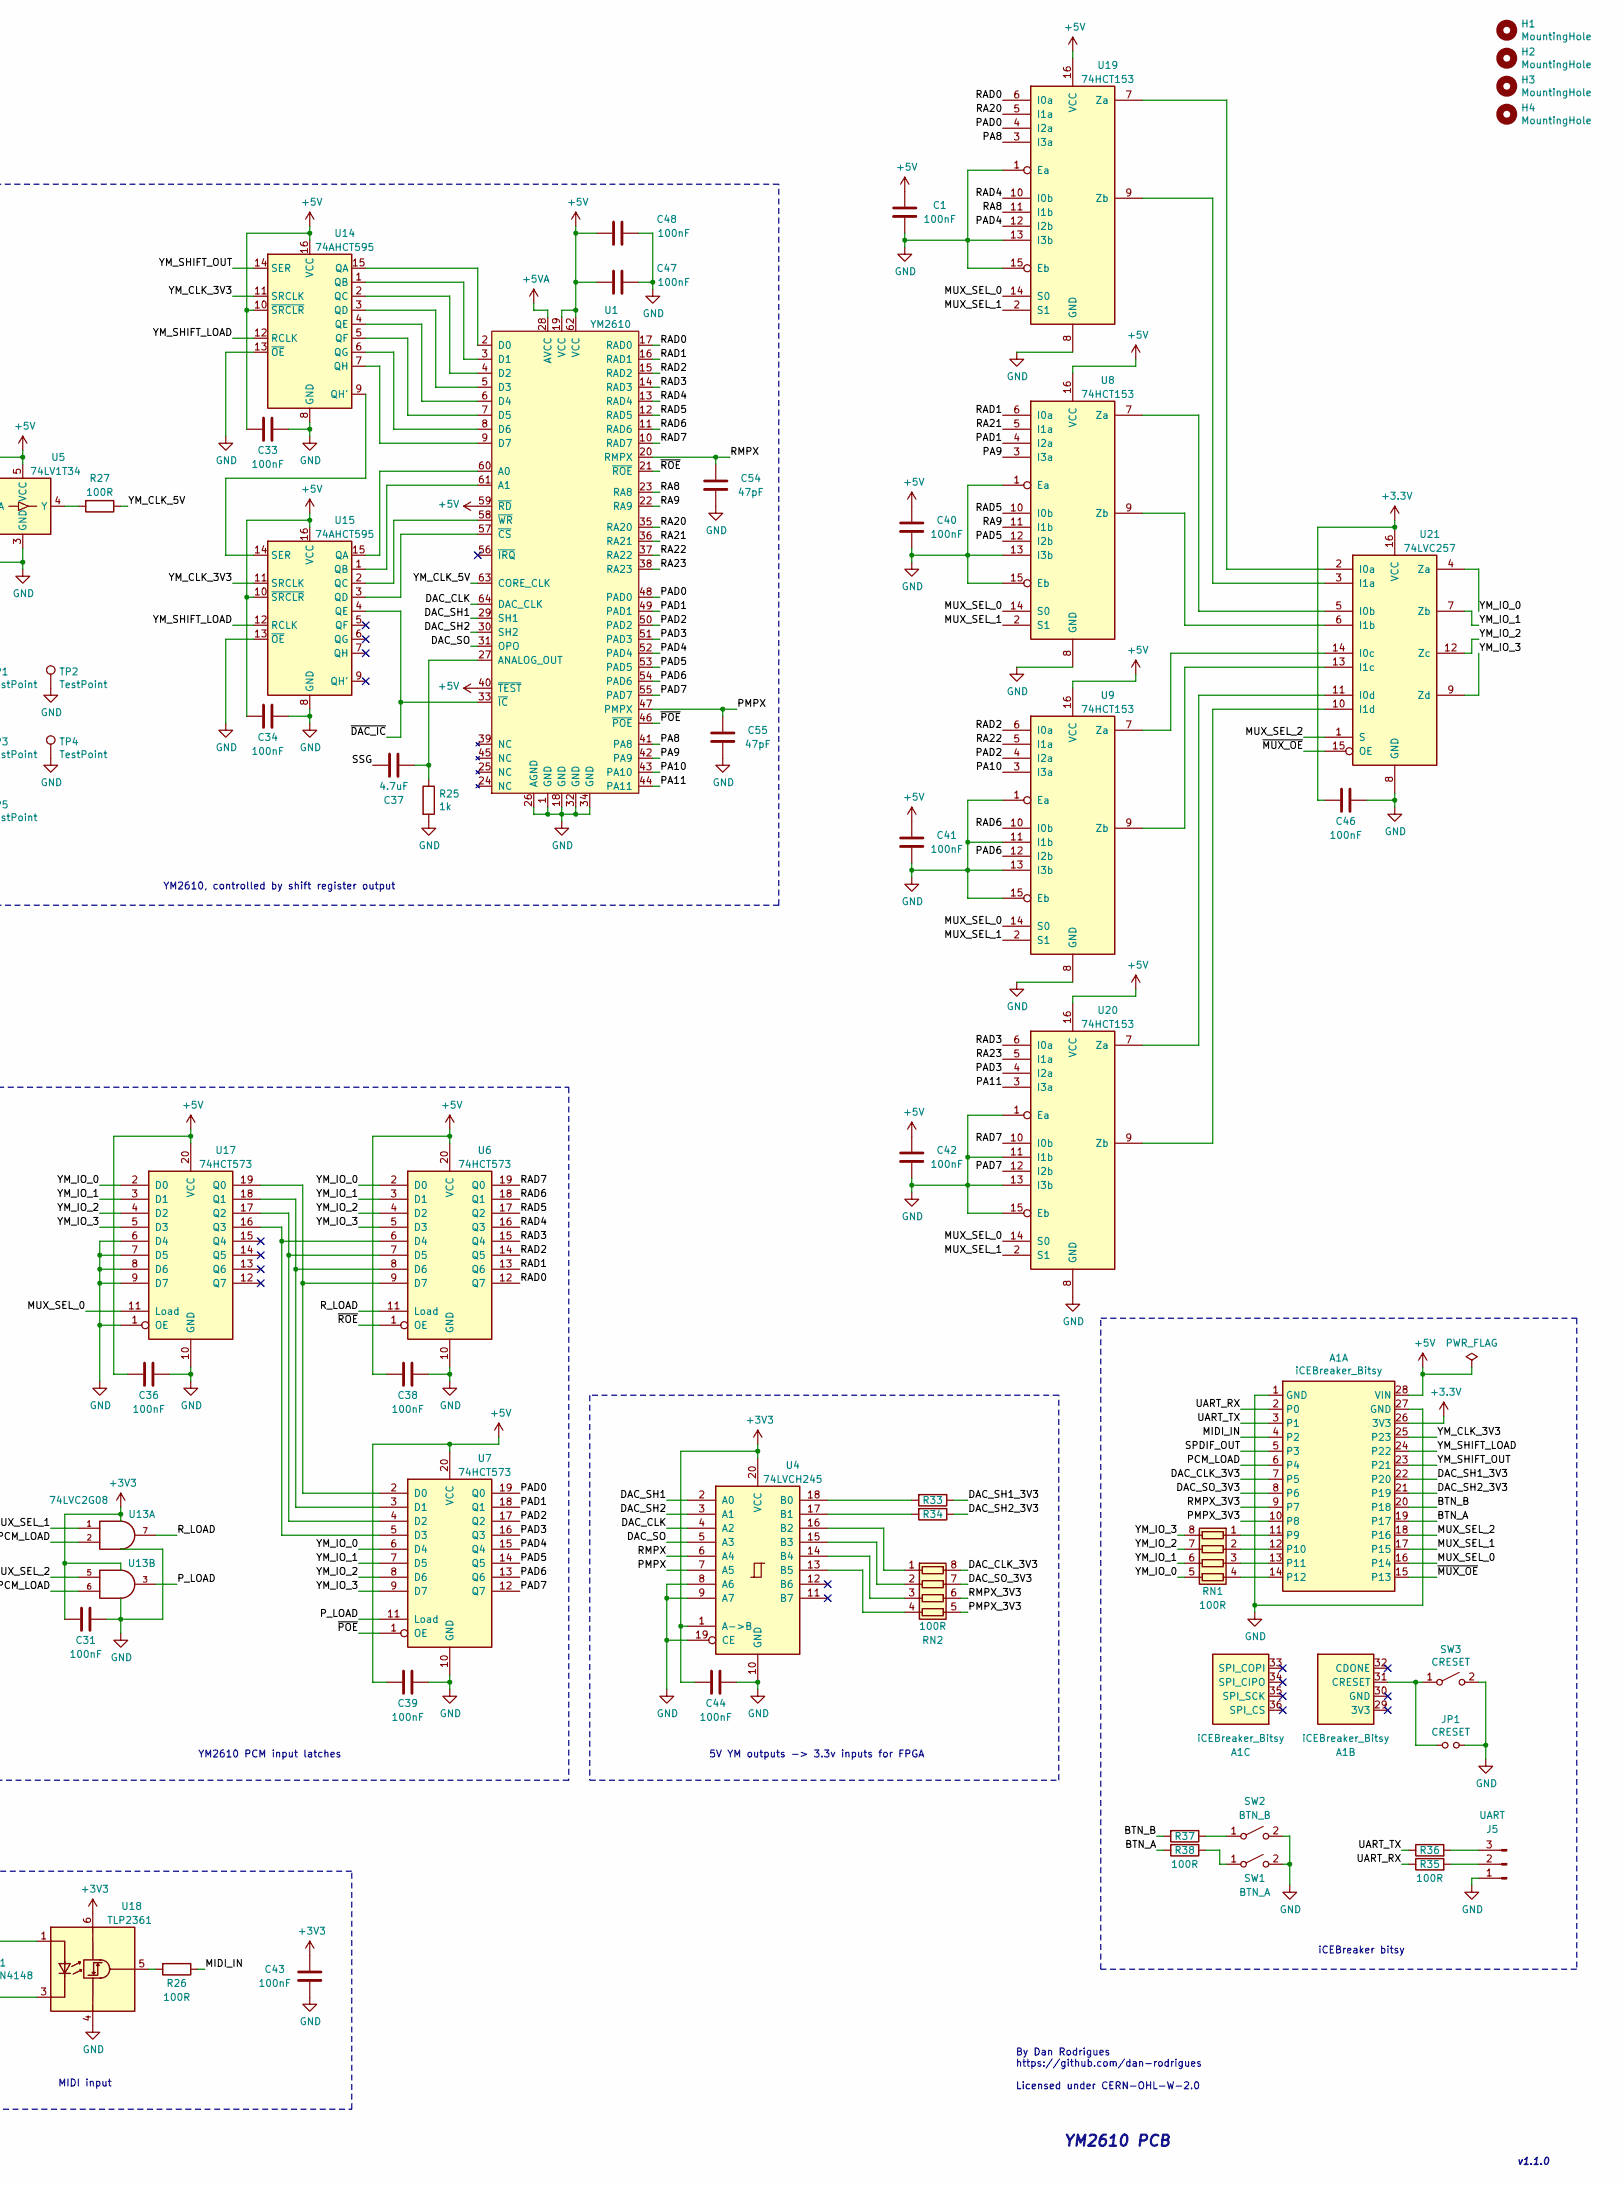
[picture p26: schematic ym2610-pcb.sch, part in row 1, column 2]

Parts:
A1: iCEBreaker_Bitsy; iCEBreaker_Bitsy_THT
C1, C29, C31, C32, C33, C34, C35, C36, C38, C39, C40, C41, C42, C44, C45, C46, C47, C48: 100nF; C_0603_1608Metric
C2, C3: 2.7nF; C_0603_1608Metric; Voltage 10v
C4, C8, C30, C51: 10uF; C_0603_1608Metric; Voltage 10v
C5, C6, C7, C17, C18, C19, C20, C22, C23, C37: 4.7uF; C_0603_1608Metric; Voltage 10v
C9, C10, C11, C12: 220pF; C_0603_1608Metric; Voltage 10v
C13: 68pF; C_0603_1608Metric; Voltage 10v
C14, C15: 47pF; C_0603_1608Metric; Voltage 10v; Tolerance 5%
C16, C28, C50: 100nF; C_0603_1608Metric; Voltage 10v
C21, C24, C25: 10nF; C_0603_1608Metric; Voltage 10v
C26, C27: 270uF; CP_Elec_6.3x7.7; Voltage 10v
C43: 100nF; C_0603_1608Metric; Voltage 3.3v
C49: 1nF; C_0603_1608Metric; Voltage 10v
C52: 150uF; CP_Elec_5x5.8; Voltage 10v
C53: 10uF; C_0603_1608Metric
C54, C55: 47pF; C_0603_1608Metric
D1: 1N4148; D_SOD-323
FB1: BLM18PG221SN1D; L_0603_1608Metric
H1, H2, H3, H4: MountingHole; MountingHole_3.2mm_M3_DIN965
J1: MIDI_IN; CUI_SDS-50J
J2: LINE_OUT; SWITCHCRAFT_35RAPC2BH3; PARTREV J
J3: HEADPHONES; SWITCHCRAFT_35RAPC2BH3; PARTREV J
J4: SPDIF_COAX; RCJ-04
J5: UART; PinHeader_1x03_P2.54mm_Vertical
JP1: CRESET; PinHeader_1x02_P2.54mm_Vertical
NT1: HEADPHONE_RETURN; NetTie-2_SMD_Pad0.5mm
NT2: DAC_CAP_NT; NetTie-2_SMD_Pad0.5mm
R1: 220R; R_0603_1608Metric
R2, R3, R4, R5: 10k; R_0603_1608Metric
R6, R7, R12, R13: 4.3k; R_0603_1608Metric; Tolerance 1%
R8, R9, R10, R11, R15, R16: 10k; R_0603_1608Metric; Tolerance 1%
R14: 33R; R_0603_1608Metric; Tolerance 1%
R17, R18, R26, R27, R28, R29, R30, R31, R32, R33, R34, R35, R36, R37, R38: 100R; R_0603_1608Metric
R19, R20: 16R; R_0603_1608Metric
R21, R22: 47k; R_0603_1608Metric
R23: 210R; R_0603_1608Metric
R24: 110R; R_0603_1608Metric
R25: 1k; R_0603_1608Metric; Tolerance 1%
R39, R40, R41, R42, R43, R44, R45, R46, R47, R48, R49, R50, R51, R52, R53, R54, R55, R56, R57, R58, R59, R60, R61, R62, R63, R64: 100k; R_0603_1608Metric
RN1, RN2: 100R; R_Array_Convex_4x0603
RV1: SSG_VOLUME; PTD901-2015K-A103
RV2: FM_PCM_VOLUME; PTD902-2020K-A103
RV3: MIX_VOLUME; PTD902-2020K-A103
SW1: BTN_A; SW_SPST_PTS645
SW2: BTN_B; SW_SPST_PTS645
SW3: CRESET; SW_SPST_PTS645
TP1, TP2, TP3, TP4, TP5: TestPoint; TestPoint_Pad_D1.0mm
U1: YM2610; DIP-64_W19.05mm_P1.78mm_Socket
U2: YM3016; DIP-16_W7.62mm_Socket
U3: 74LVC1G34; SOT-353_SC-70-5
U4: 74LVCH245; TSSOP-20_4.4x6.5mm_P0.65mm
U5: 74LV1T34; SOT-23-5
U6, U7, U17: 74HCT573; TSSOP-20_4.4x6.5mm_P0.65mm
U8, U9, U19, U20: 74HCT153; TSSOP-16_4.4x5mm_P0.65mm
U10, U11: TSV914IPT; TSSOP-14_4.4x5mm_P0.65mm
U12: AD8532; TSSOP-8_4.4x3mm_P0.65mm
U13: 74LVC2G08; TSSOP-8_3x3mm_P0.65mm
U14, U15: 74AHCT595; TSSOP-16_4.4x5mm_P0.65mm
U16: SPDIF_OPTICAL; FCR684208T
U18: TLP2361; SOIC-6-5_W4.55mm
U21: 74LVC257; TSSOP-16_4.4x5mm_P0.65mm

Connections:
+5V: A1.28 (VIN), C1.2, C25.1, C33.2, C34.2, C36.1, C38.2, C39.2, C40.2, C41.2, C42.2, C45.2, C47.2, C48.2, FB1.2, R39.1, R40.1, R41.1, R42.1, R43.1, R44.1, R45.1, R46.1, R47.1, R48.1, R49.1, R50.1, R51.1, R52.1, R53.1, R54.1, R55.1, R56.1, R57.1, R58.1, R59.1, R60.1, R61.1, R62.1, R63.1, R64.1, U1.19 (VCC), U1.40 (~TEST), U1.59 (~RD), U1.62 (VCC), U5.5 (VCC), U6.20 (VCC), U7.20 (VCC), U8.16 (VCC), U9.16 (VCC), U14.10 (~SRCLR), U14.16 (VCC), U15.10 (~SRCLR), U15.16 (VCC), U17.20 (VCC), U19.16 (VCC), U20.16 (VCC)
+5VA: C16.1, C21.1, C24.1, C28.1, C30.1, FB1.1, R28.2, U1.28 (AVCC), U10.4 (V+), U11.4 (V+), U12.8 (V+)
/BTN_A: A1.19 (P17), R38.2
/BTN_B: A1.20 (P18), R37.2
/DAC_5V: C4.2, C50.2, C52.1, R28.1, U2.1 (VDD), U2.3 (VDD), U2.6 (FORM)
/DAC_CH1: C2.1, U2.10 (CH1), U10.10 (+)
/DAC_CH2: C3.1, U2.11 (CH2), U10.12 (+)
/DAC_CLK: R29.2, U1.64 (DAC_CLK), U4.4 (A2)
/DAC_CLK_3V3: A1.7 (P5), RN2.8 (R1.2)
/DAC_SH1: R31.2, U1.29 (SH1), U4.2 (A0)
/DAC_SH1_3V3: A1.22 (P20), R33.1
/DAC_SH2: R32.2, U1.30 (SH2), U4.3 (A1)
/DAC_SH2_3V3: A1.21 (P19), R34.1
/DAC_SO: R30.2, U1.31 (OPO), U4.5 (A3)
/DAC_SO_3V3: A1.8 (P6), RN2.7 (R2.2)
/FILTERED_CH1: C19.1, RV2.6
/FILTERED_CH2: C20.1, RV2.3
/HEADPHONE_L: R4.1, R19.2, U12.1
/HEADPHONE_R: R5.1, R20.2, U12.7
/LINE_L: C17.1, R17.2, RV3.3
/LINE_R: C18.1, R18.2, RV3.6
/MIDI_IN: A1.4 (P2), R26.1
/MUX_SEL_0: A1.16 (P14), U8.14 (S0), U9.14 (S0), U17.11 (Load), U19.14 (S0), U20.14 (S0)
/MUX_SEL_1: A1.17 (P15), U8.2 (S1), U9.2 (S1), U13.1, U19.2 (S1), U20.2 (S1)
/MUX_SEL_2: A1.18 (P16), U13.5, U21.1 (S)
/PA8: R61.2, U1.41 (PA8), U19.3 (I3a)
/PA9: R62.2, U1.42 (PA9), U8.3 (I3a)
/PA10: R63.2, U1.43 (PA10), U9.3 (I3a)
/PA11: R64.2, U1.44 (PA11), U20.3 (I3a)
/PAD0: R39.2, U1.48 (PAD0), U7.19 (Q0), U19.4 (I2a)
/PAD1: R40.2, U1.49 (PAD1), U7.18 (Q1), U8.4 (I2a)
/PAD2: R41.2, U1.50 (PAD2), U7.17 (Q2), U9.4 (I2a)
/PAD3: R42.2, U1.51 (PAD3), U7.16 (Q3), U20.4 (I2a)
/PAD4: R43.2, U1.52 (PAD4), U7.15 (Q4), U19.12 (I2b)
/PAD5: R44.2, U1.53 (PAD5), U7.14 (Q5), U8.12 (I2b)
/PAD6: R45.2, U1.54 (PAD6), U7.13 (Q6), U9.12 (I2b)
/PAD7: R46.2, U1.55 (PAD7), U7.12 (Q7), U20.12 (I2b)
/PCM_LOAD: A1.6 (P4), U13.2, U13.6
/PMPX: C55.2, U1.47 (PMPX), U4.7 (A5)
/PMPX_3V3: A1.10 (P8), RN2.5 (R4.2)
/P_LOAD: U7.11 (Load), U13.3
/RA8: R55.2, U1.23 (RA8), U19.11 (I1b)
/RA9: R56.2, U1.22 (RA9), U8.11 (I1b)
/RA20: R57.2, U1.35 (RA20), U19.5 (I1a)
/RA21: R58.2, U1.36 (RA21), U8.5 (I1a)
/RA22: R59.2, U1.37 (RA22), U9.5 (I1a)
/RA23: R60.2, U1.38 (RA23), U20.5 (I1a)
/RAD0: R47.2, U1.17 (RAD0), U6.12 (Q7), U19.6 (I0a)
/RAD1: R48.2, U1.16 (RAD1), U6.13 (Q6), U8.6 (I0a)
/RAD2: R49.2, U1.15 (RAD2), U6.14 (Q5), U9.6 (I0a)
/RAD3: R50.2, U1.14 (RAD3), U6.15 (Q4), U20.6 (I0a)
/RAD4: R51.2, U1.13 (RAD4), U6.16 (Q3), U19.10 (I0b)
/RAD5: R52.2, U1.12 (RAD5), U6.17 (Q2), U8.10 (I0b)
/RAD6: R53.2, U1.11 (RAD6), U6.18 (Q1), U9.10 (I0b)
/RAD7: R54.2, U1.10 (RAD7), U6.19 (Q0), U20.10 (I0b)
/RB_2V5: C8.1, C51.2, U2.16 (RB), U10.3 (+), U11.10 (+), U11.12 (+), U12.3 (+), U12.5 (+)
/RMPX: C54.2, U1.20 (RMPX), U4.6 (A4)
/RMPX_3V3: A1.9 (P7), RN2.6 (R3.2)
/R_LOAD: U6.11 (Load), U13.7
/SPDIF_OUT: A1.5 (P3), U3.2, U16.3 (Input)
/SSG: C37.2, RV1.3
/UART_RX: A1.2 (P0), R35.1
/UART_TX: A1.3 (P1), R36.1
/YM_CLK_3V3: A1.25 (P23), U5.2 (A), U14.11 (SRCLK), U15.11 (SRCLK)
/YM_CLK_5V: R27.1, U1.63 (CORE_CLK)
/YM_IO_0: RN1.5 (R4.2), U6.2 (D0), U7.6 (D4), U17.2 (D0), U21.4 (Za)
/YM_IO_1: RN1.6 (R3.2), U6.3 (D1), U7.7 (D5), U17.3 (D1), U21.7 (Zb)
/YM_IO_2: RN1.7 (R2.2), U6.4 (D2), U7.8 (D6), U17.4 (D2), U21.12 (Zc)
/YM_IO_3: RN1.8 (R1.2), U6.5 (D3), U7.9 (D7), U17.5 (D3), U21.9 (Zd)
/YM_SHIFT_LOAD: A1.24 (P22), U14.12 (RCLK), U15.12 (RCLK)
/YM_SHIFT_OUT: A1.23 (P21), U14.14 (SER)
/~DAC_IC: U1.33 (~IC), U2.9 (~ICL), U15.4 (QE)
/~MUX_OE: A1.15 (P13), U21.15 (OE)
/~POE: U1.46 (~POE), U7.1 (OE)
/~ROE: U1.21 (~ROE), U6.1 (OE)
GND: A1.1 (GND), A1.27 (GND), C1.1, C2.2, C3.2, C4.1, C8.2, C10.1, C12.1, C13.2, C16.2, C21.2, C24.2, C25.2, C28.2, C29.1, C30.2, C31.2, C32.1, C33.1, C34.1, C36.2, C38.1, C39.1, C40.1, C41.1, C42.1, C43.1, C44.1, C45.1, C46.1, C47.1, C48.1, C50.1, C51.1, C53.1, C54.1, C55.1, J2.1, J4.1, J5.1, JP1.2, NT1.2, NT2.2, R21.1, R22.1, R24.1, R25.2, RV1.1, RV2.1, RV2.4, RV3.1, RV3.4, SW1.2 (B), SW2.2 (B), SW3.2 (B), TP1.1, TP2.1, TP3.1, TP4.1, TP5.1, U1.1 (GND), U1.18 (GND), U1.26 (AGND), U1.32 (GND), U1.34 (GND), U2.2 (GND), U3.3 (GND), U4.8 (A6), U4.9 (A7), U4.10 (GND), U4.19 (CE), U5.3 (GND), U6.10 (GND), U7.10 (GND), U8.1 (Ea), U8.8 (GND), U8.13 (I3b), U8.15 (Eb), U9.1 (Ea), U9.8 (GND), U9.11 (I1b), U9.13 (I3b), U9.15 (Eb), U10.11 (V-), U11.11 (V-), U12.4 (V-), U13.4 (GND), U14.8 (GND), U14.13 (~OE), U15.8 (GND), U15.13 (~OE), U16.1 (GND), U17.1 (OE), U17.6 (D4), U17.7 (D5), U17.8 (D6), U17.9 (D7), U17.10 (GND), U18.4 (GND), U19.1 (Ea), U19.8 (GND), U19.13 (I3b), U19.15 (Eb), U20.1 (Ea), U20.8 (GND), U20.11 (I1b), U20.13 (I3b), U20.15 (Eb), U21.8 (GND)
unnamed: A1.11 (P9), RN1.1 (R1.1)
unnamed: A1.12 (P10), RN1.2 (R2.1)
unnamed: A1.13 (P11), RN1.3 (R3.1)
unnamed: A1.14 (P12), RN1.4 (R4.1)
unnamed: A1.31 (CRESET), JP1.1, SW3.1 (A)
unnamed: C5.1, R8.2
unnamed: C5.2, RV2.5
unnamed: C6.1, R10.2
unnamed: C6.2, RV2.2
unnamed: C7.1, R9.2, R11.2
unnamed: C7.2, RV1.2
unnamed: C9.2, R6.1, R12.2
unnamed: C10.2, R12.1, U11.3 (+)
unnamed: C11.1, C20.2, U11.6 (-), U11.7
unnamed: C11.2, R7.1, R13.2
unnamed: C12.2, R13.1, U11.5 (+)
unnamed: C13.1, U2.13 (To_BUFF), U10.5 (+)
unnamed: C14.1, C17.2, R15.1, U11.8
unnamed: C14.2, R8.1, R9.1, R15.2, U11.9 (-)
unnamed: C15.1, C18.2, R16.1, U11.14
unnamed: C15.2, R10.1, R11.1, R16.2, U11.13 (-)
unnamed: C9.1, C19.2, U11.1, U11.2 (-)
unnamed: C22.1, R2.2
unnamed: C22.2, RV3.2
unnamed: C23.1, R3.2
unnamed: C23.2, RV3.5
unnamed: C26.1, R19.1
unnamed: C26.2, J3.5, R21.2
unnamed: C27.1, R20.1
unnamed: C27.2, J3.2, R22.2
unnamed: C35.1, J4.2
unnamed: C35.2, R23.1, R24.2
unnamed: C37.1, R25.1, U1.27 (ANALOG_OUT)
unnamed: C49.1, U2.14 (MP), U10.1
unnamed: C49.2, U2.15 (BC), U10.2 (-)
unnamed: C52.2, NT2.1
unnamed: D1.1 (K), R1.1, U18.1 (A)
unnamed: D1.2 (A), J1.5, U18.3 (K)
unnamed: J1.4, R1.2
unnamed: J2.2, R18.1
unnamed: J2.5, R17.1
unnamed: J3.1, NT1.1
unnamed: J5.2, R35.2
unnamed: J5.3, R36.2
unnamed: R2.1, R4.2, U12.2 (-)
unnamed: R3.1, R5.2, U12.6 (-)
unnamed: R6.2, U10.8, U10.9 (-)
unnamed: R7.2, U10.13 (-), U10.14
unnamed: R14.1, U10.6 (-), U10.7
unnamed: R14.2, U2.12 (COM)
unnamed: R23.2, U3.4
unnamed: R26.2, U18.5 (VO)
unnamed: R27.2, U5.4 (Y)
unnamed: R29.1, U2.5 (CLK)
unnamed: R30.1, U2.4 (SD)
unnamed: R31.1, U2.8 (SAM1)
unnamed: R32.1, U2.7 (SAM2)
unnamed: R33.2, U4.18 (B0)
unnamed: R34.2, U4.17 (B1)
unnamed: R37.1, SW2.1 (A)
unnamed: R38.1, SW1.1 (A)
unnamed: RN2.1 (R1.1), U4.16 (B2)
unnamed: RN2.2 (R2.1), U4.15 (B3)
unnamed: RN2.3 (R3.1), U4.14 (B4)
unnamed: RN2.4 (R4.1), U4.13 (B5)
unnamed: U1.2 (D0), U14.15 (QA)
unnamed: U1.3 (D1), U14.1 (QB)
unnamed: U1.4 (D2), U14.2 (QC)
unnamed: U1.5 (D3), U14.3 (QD)
unnamed: U1.6 (D4), U14.4 (QE)
unnamed: U1.7 (D5), U14.5 (QF)
unnamed: U1.8 (D6), U14.6 (QG)
unnamed: U1.9 (D7), U14.7 (QH)
unnamed: U1.57 (~CS), U15.3 (QD)
unnamed: U1.58 (~WR), U15.2 (QC)
unnamed: U1.60 (A0), U15.15 (QA)
unnamed: U1.61 (A1), U15.1 (QB)
unnamed: U14.9 (QH'), U15.14 (SER)
unnamed: U6.6 (D4), U7.5 (D3), U17.16 (Q3)
unnamed: U6.7 (D5), U7.4 (D2), U17.17 (Q2)
unnamed: U6.8 (D6), U7.3 (D1), U17.18 (Q1)
unnamed: U6.9 (D7), U7.2 (D0), U17.19 (Q0)
unnamed: U19.7 (Za), U21.2 (I0a)
unnamed: U19.9 (Zb), U21.3 (I1a)
unnamed: U20.7 (Za), U21.11 (I0d)
unnamed: U20.9 (Zb), U21.10 (I1d)
unnamed: U8.7 (Za), U21.5 (I0b)
unnamed: U8.9 (Zb), U21.6 (I1b)
unnamed: U9.9 (Zb), U21.13 (I1c)
unnamed: U9.7 (Za), U21.14 (I0c)

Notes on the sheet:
Sallen-Key low pass filter (fc = 16.8KHz) A similar one is used in the Neo-Geo system, a 1990 arcade games platform also using the YM2610/3016. The cutoff frequency was raised slightly and mismatched caps replaced with matching pairs.
VBUS filter
2x pots provided for attenuation for the analog (SSG) and digital (FM/PCM) sources. 1x pot for attenuating headphone output
If the intent was to be S/PDIF spec. compliant there would probably be a transformer on the coax output. Haven’t observed any issues with the 48KHz sampling rate that’s used in this project.
An FCR684208T TX module is used instead of the Toshiba ones. Advantages to using these: * Much cheaper * Works with VCC = 3.3v * Doesn’t require extra resistors as they are included in the module (a bit like the obsolete TOTX179)
3.5mm audio outputs
S/PDIF-compatible outputs
MIDI input
Pullups for YM2610 outputs to HCT153
DAC (FM / Digital sound sources only) SSG analog (YM2149) is output direct from YM2610
YM2610 PCM input latches
YM2610, controlled by shift register output
5V YM outputs -> 3.3v inputs for FPGA
iCEBreaker bitsy
Opamp power
YM2610 PCB
v1.1.0
By Dan Rodrigues https://github.com/dan-rodrigues Licensed under CERN-OHL-W-2.0

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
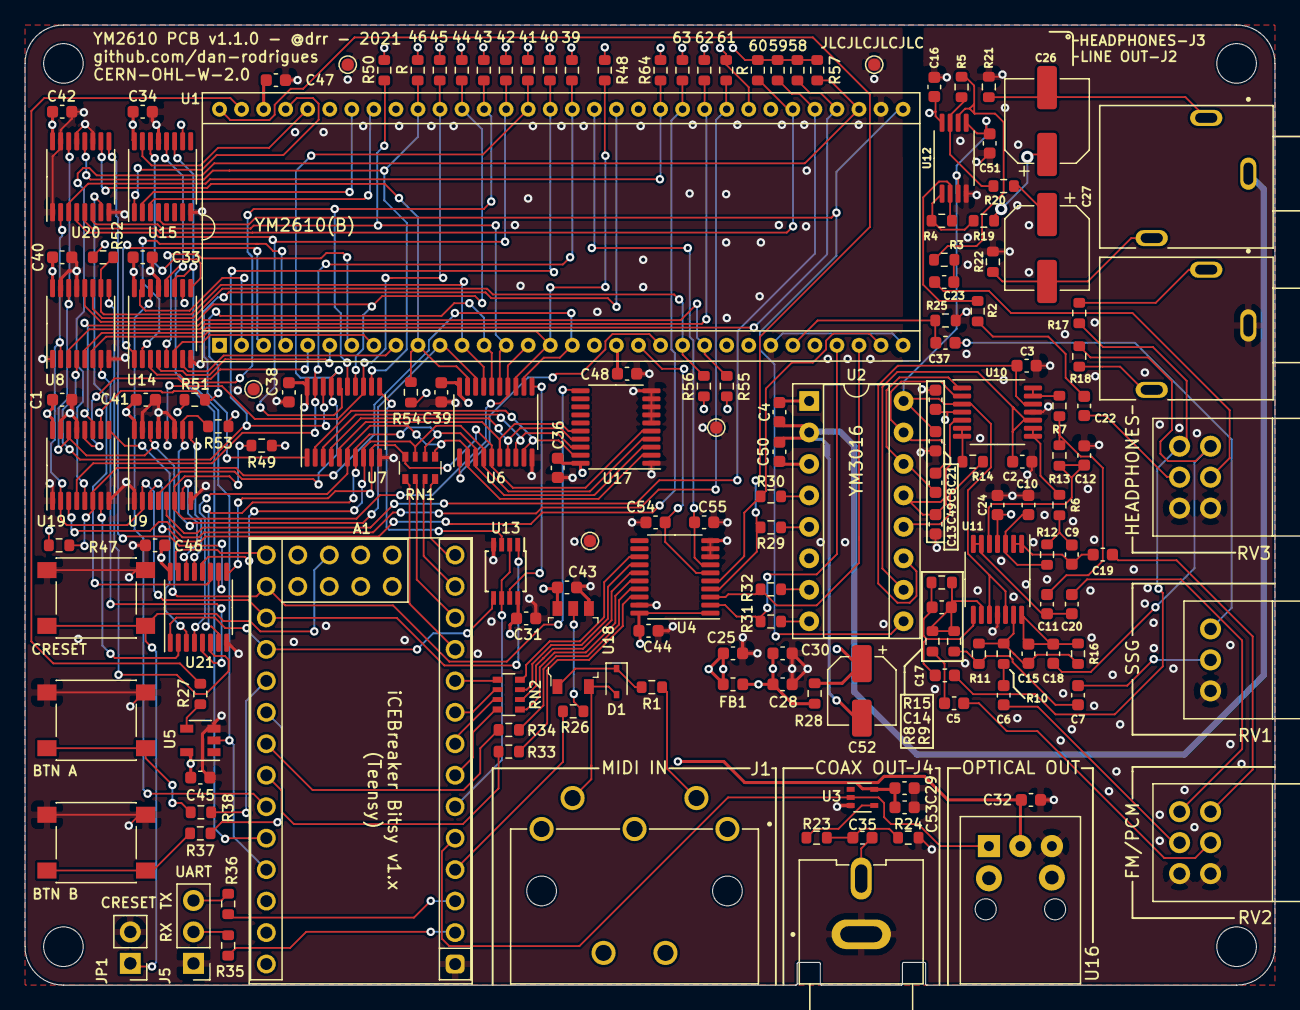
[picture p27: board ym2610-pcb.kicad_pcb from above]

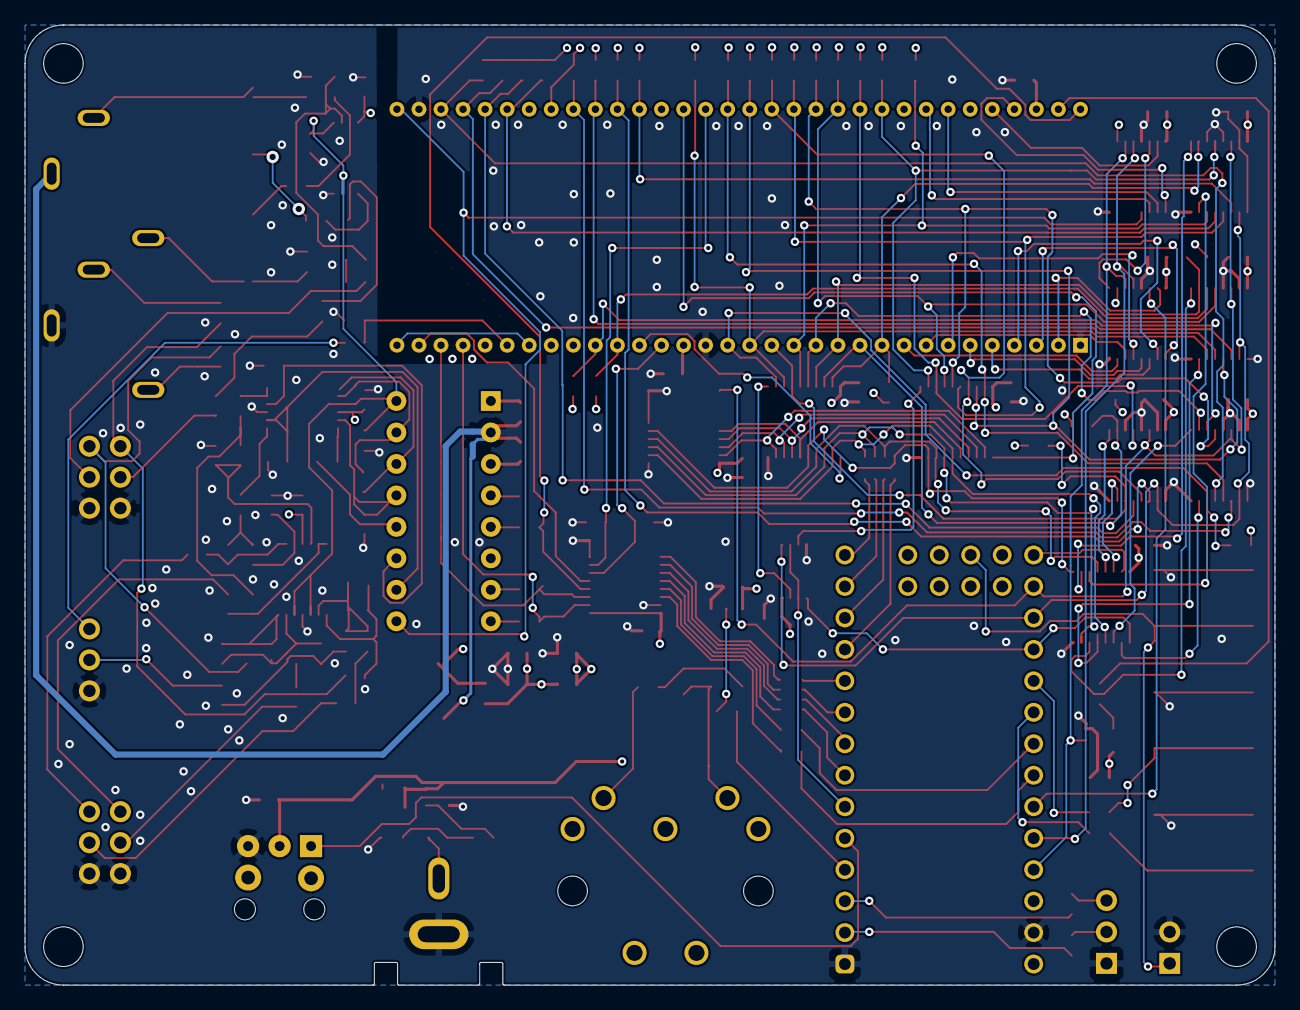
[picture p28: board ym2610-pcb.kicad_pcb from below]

Board: 4 copper layers, 100.9 x 77.5 mm, 168 parts (2 on the bottom side), 167 nets.

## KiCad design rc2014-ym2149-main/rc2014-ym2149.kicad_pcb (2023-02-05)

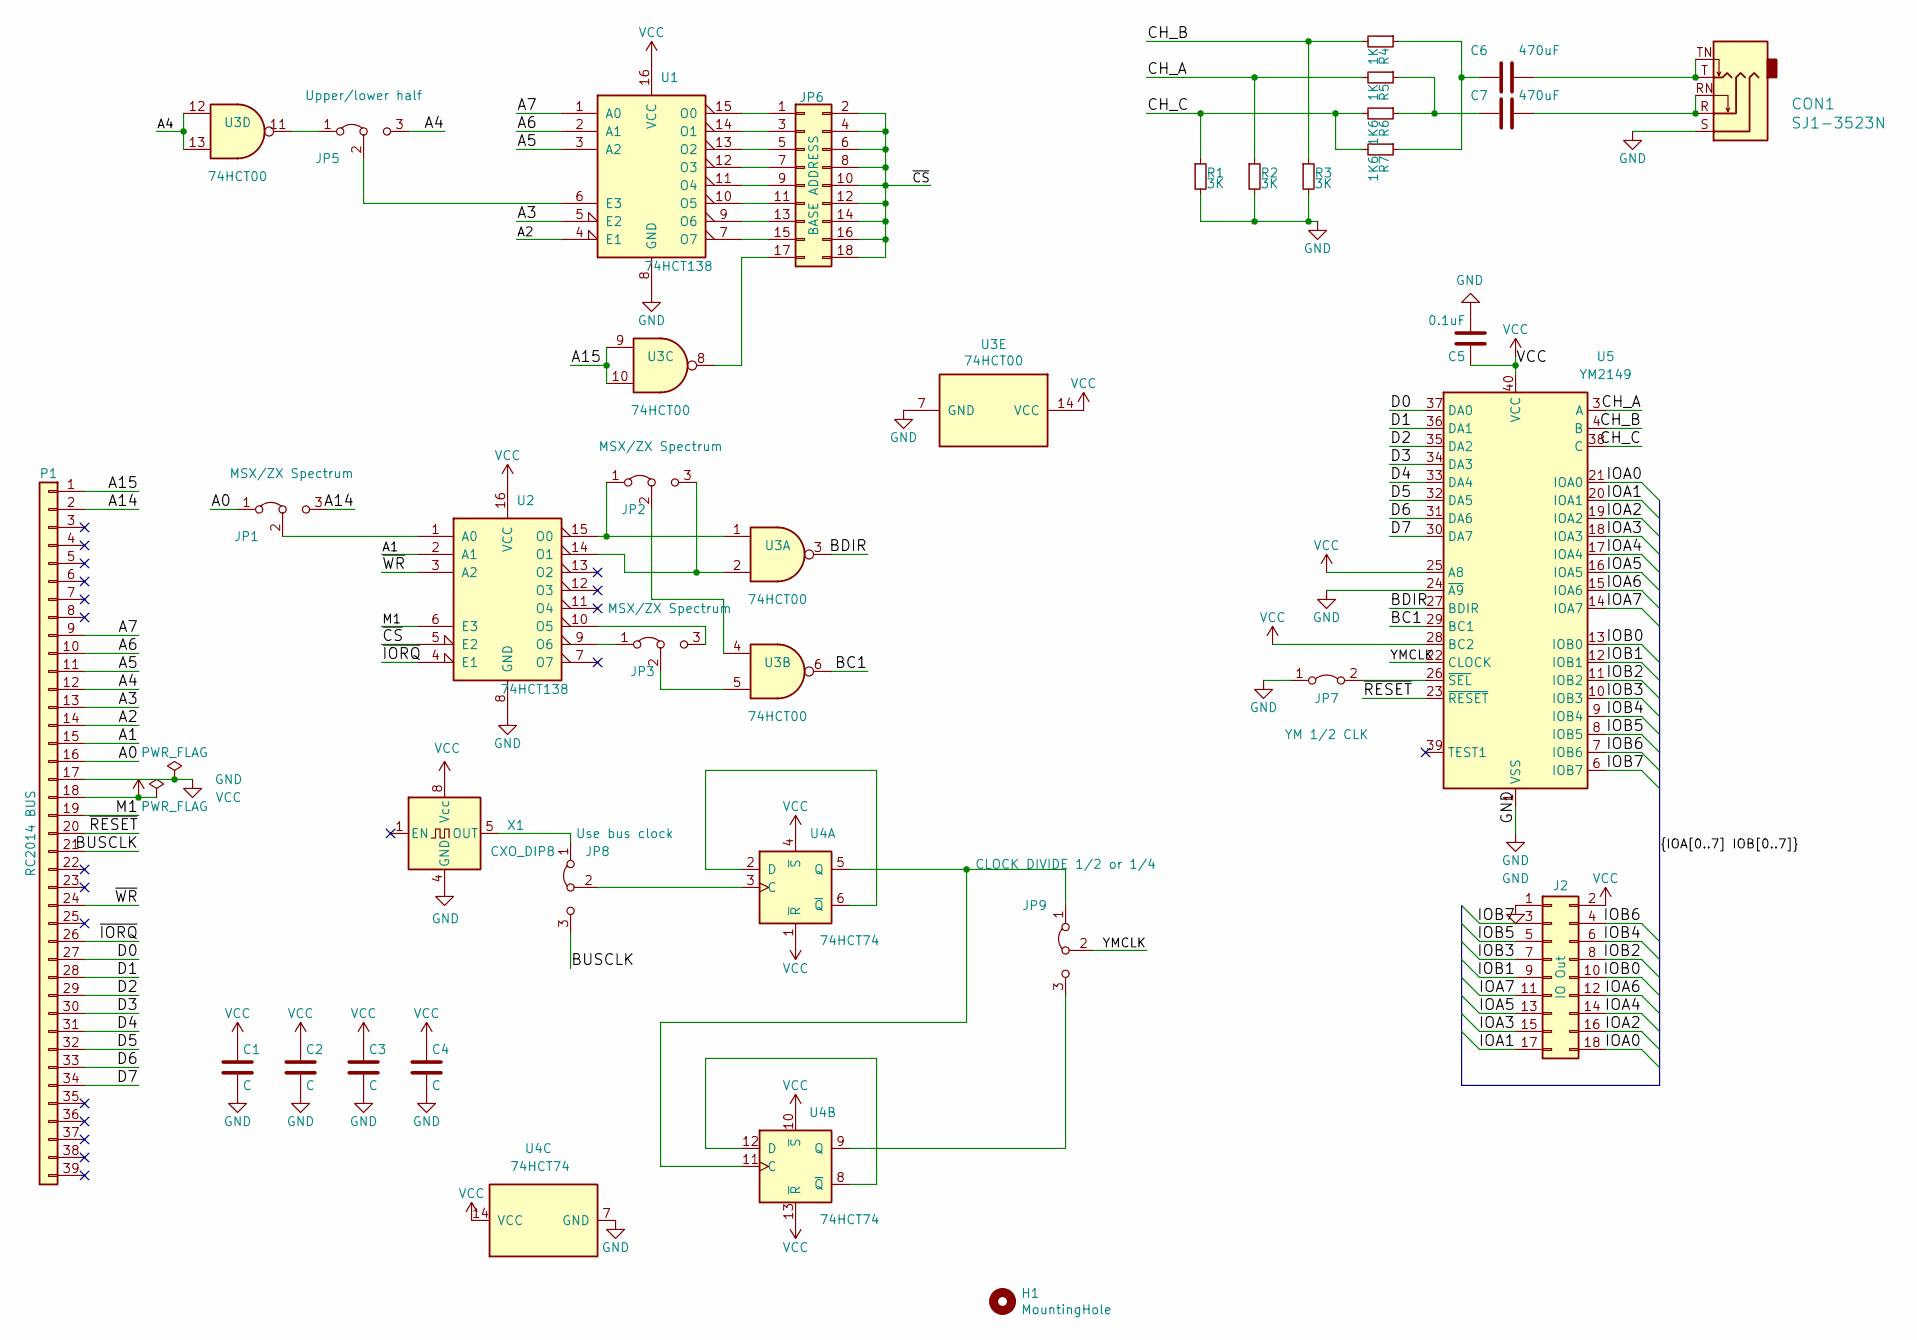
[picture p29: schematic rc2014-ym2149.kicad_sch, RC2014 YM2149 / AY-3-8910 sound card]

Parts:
C1, C2, C3, C4: C; C_Disc_D3.8mm_W2.6mm_P2.50mm
C5: 0.1uF; C_Disc_D3.8mm_W2.6mm_P2.50mm
C6, C7: 470uF; CP_Radial_D6.3mm_P2.50mm
CON1: SJ1-3523N; Headphone_Jack_3.5mm_5_pin
H1: MountingHole; MountingHole_3.2mm_M3
J2: IO Out; PinHeader_2x09_P2.54mm_Vertical
JP1, JP2, JP3: MSX/ZX Spectrum; PinHeader_1x03_P2.54mm_Vertical
JP5: Upper/lower half; PinHeader_1x03_P2.54mm_Vertical
JP6: BASE ADDRESS; PinHeader_2x09_P2.54mm_Vertical
JP7: YM 1/2 CLK; PinHeader_1x02_P2.54mm_Vertical
JP8: Use bus clock; PinHeader_1x03_P2.54mm_Vertical
JP9: CLOCK DIVIDE 1/2 or 1/4; PinHeader_1x03_P2.54mm_Vertical
P1: RC2014 BUS; PinHeader_1x39_P2.54mm_Vertical
R1, R2, R3: 3K; R_Axial_DIN0207_L6.3mm_D2.5mm_P10.16mm_Horizontal
R4, R5: 1K; R_Axial_DIN0207_L6.3mm_D2.5mm_P10.16mm_Horizontal
R6, R7: 1K6; R_Axial_DIN0207_L6.3mm_D2.5mm_P10.16mm_Horizontal
U1, U2: 74HCT138; DIP-16_W7.62mm_Socket_LongPads
U3: 74HCT00; DIP-14_W7.62mm_Socket_LongPads
U4: 74HCT74; DIP-14_W7.62mm_Socket_LongPads
U5: YM2149; DIP-40_W15.24mm_Socket_LongPads
X1: CXO_DIP8; DIP-8_W7.62mm_Socket_LongPads

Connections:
/A0: JP1.1 (A), P1.16
/A1: P1.15, U2.2 (A1)
/A2: P1.14, U1.4 (E1)
/A3: P1.13, U1.5 (E2)
/A4: JP5.3 (B), P1.12, U3.12, U3.13
/A5: P1.11, U1.3 (A2)
/A6: P1.10, U1.2 (A1)
/A7: P1.9, U1.1 (A0)
/A14: JP1.3 (B), P1.2
/A15: P1.1, U3.9, U3.10
/BC1: U3.6, U5.29 (BC1)
/BDIR: U3.3, U5.27 (BDIR)
/BUSCLK: JP8.3 (B), P1.21
/CH_A: R2.1, R5.2, U5.3 (A)
/CH_B: R3.1, R4.2, U5.4 (B)
/CH_C: R1.1, R6.2, R7.2, U5.38 (C)
/D0: P1.27, U5.37 (DA0)
/D1: P1.28, U5.36 (DA1)
/D2: P1.29, U5.35 (DA2)
/D3: P1.30, U5.34 (DA3)
/D4: P1.31, U5.33 (DA4)
/D5: P1.32, U5.32 (DA5)
/D6: P1.33, U5.31 (DA6)
/D7: P1.34, U5.30 (DA7)
/IOA0: J2.18, U5.21 (IOA0)
/IOA1: J2.17, U5.20 (IOA1)
/IOA2: J2.16, U5.19 (IOA2)
/IOA3: J2.15, U5.18 (IOA3)
/IOA4: J2.14, U5.17 (IOA4)
/IOA5: J2.13, U5.16 (IOA5)
/IOA6: J2.12, U5.15 (IOA6)
/IOA7: J2.11, U5.14 (IOA7)
/IOB0: J2.10, U5.13 (IOB0)
/IOB1: J2.9, U5.12 (IOB1)
/IOB2: J2.8, U5.11 (IOB2)
/IOB3: J2.7, U5.10 (IOB3)
/IOB4: J2.6, U5.9 (IOB4)
/IOB5: J2.5, U5.8 (IOB5)
/IOB6: J2.4, U5.7 (IOB6)
/IOB7: J2.3, U5.6 (IOB7)
/M1: P1.19, U2.6 (E3)
/YMCLK: JP9.2 (C), U5.22 (CLOCK)
/~CS: JP6.2, JP6.4, JP6.6, JP6.8, JP6.10, JP6.12, JP6.14, JP6.16, JP6.18, U2.5 (E2)
/~IORQ: P1.26, U2.4 (E1)
/~RESET: P1.20, U5.23 (~RESET)
/~WR: P1.24, U2.3 (A2)
GND: C1.2, C2.2, C3.2, C4.2, C5.2, CON1.S, J2.1, JP7.1 (A), P1.17, R1.2, R2.2, R3.2, U1.8 (GND), U2.8 (GND), U3.7 (GND), U4.7 (GND), U5.1 (VSS), U5.24 (~A9), X1.4 (GND)
unnamed: C6.1, R4.1, R7.1
unnamed: C6.2, CON1.T, CON1.TN
unnamed: C7.1, R5.1, R6.1
unnamed: C7.2, CON1.R, CON1.RN
unnamed: JP1.2 (C), U2.1 (A0)
unnamed: JP2.1 (A), U2.15 (O0), U3.1
unnamed: JP2.2 (C), U3.4
unnamed: JP2.3 (B), U2.14 (O1), U3.2
unnamed: JP3.1 (A), U2.9 (O6)
unnamed: JP3.2 (C), U3.5
unnamed: JP3.3 (B), U2.10 (O5)
unnamed: JP5.1 (A), U3.11
unnamed: JP5.2 (C), U1.6 (E3)
unnamed: JP6.1, U1.15 (O0)
unnamed: JP6.3, U1.14 (O1)
unnamed: JP6.5, U1.13 (O2)
unnamed: JP6.7, U1.12 (O3)
unnamed: JP6.9, U1.11 (O4)
unnamed: JP6.11, U1.10 (O5)
unnamed: JP6.13, U1.9 (O6)
unnamed: JP6.15, U1.7 (O7)
unnamed: JP6.17, U3.8
unnamed: JP7.2 (B), U5.26 (~SEL)
unnamed: JP8.1 (A), X1.5 (OUT)
unnamed: JP8.2 (C), U4.3 (C)
unnamed: JP9.1 (A), U4.5 (Q), U4.11 (C)
unnamed: JP9.3 (B), U4.9 (Q)
unnamed: U4.2 (D), U4.6 (~Q)
unnamed: U4.8 (~Q), U4.12 (D)
VCC: C1.1, C2.1, C3.1, C4.1, C5.1, J2.2, P1.18, U1.16 (VCC), U2.16 (VCC), U3.14 (VCC), U4.1 (~R), U4.4 (~S), U4.10 (~S), U4.13 (~R), U4.14 (VCC), U5.25 (A8), U5.28 (BC2), U5.40 (VCC), X1.8 (Vcc)

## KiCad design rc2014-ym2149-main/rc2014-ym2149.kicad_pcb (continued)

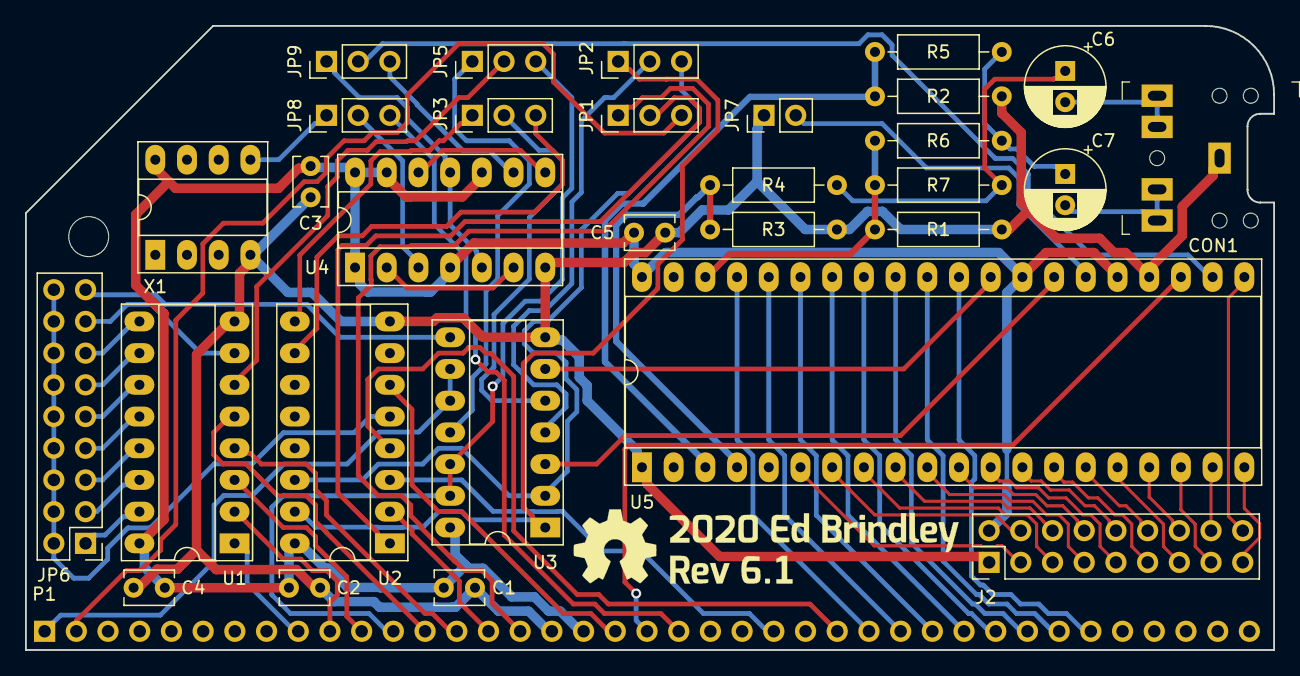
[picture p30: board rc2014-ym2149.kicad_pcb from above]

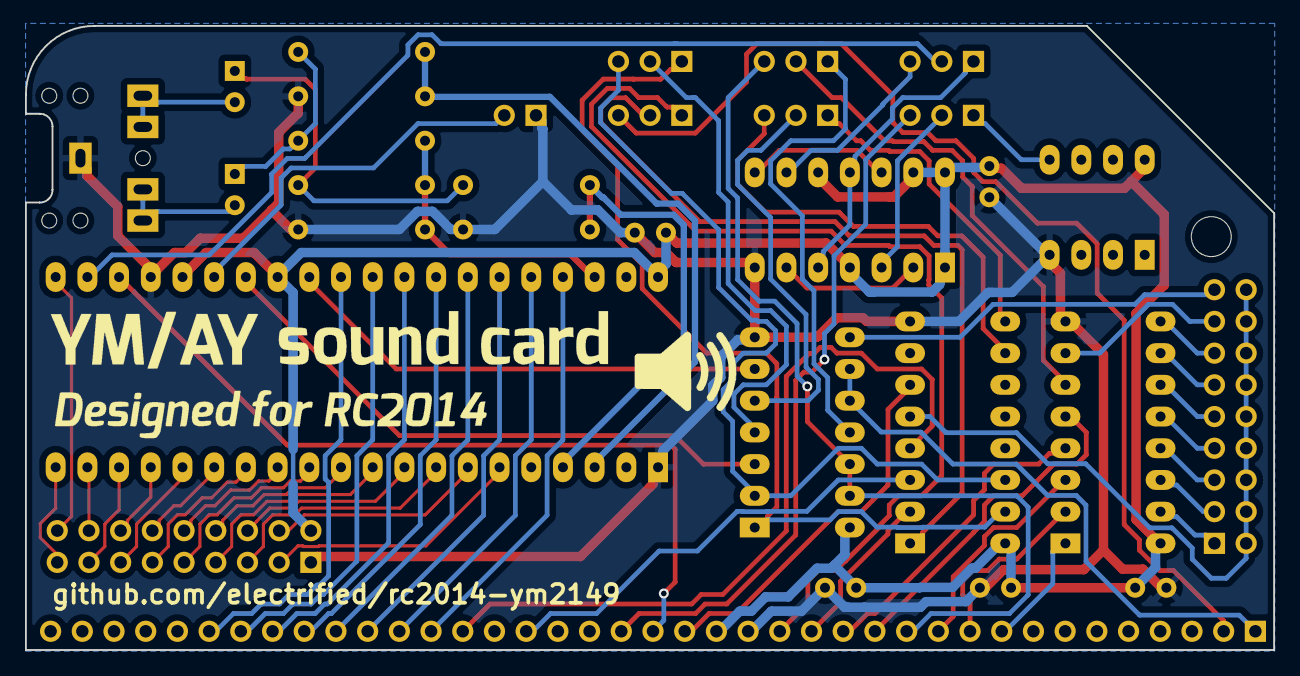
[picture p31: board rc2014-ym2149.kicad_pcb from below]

Board: 2 copper layers, 100.0 x 50.0 mm, 35 parts (2 on the bottom side), 77 nets.

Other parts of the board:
G1: LOGO; ym_text2
G2: LOGO; designed_for_rc2014
G5: LOGO; rev61

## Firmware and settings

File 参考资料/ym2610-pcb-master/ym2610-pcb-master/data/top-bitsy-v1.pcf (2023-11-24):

# YM2610 PCM Mux (discrete logic)

set_io ym_io[0] 20
set_io ym_io[1] 13
set_io ym_io[2] 21
set_io ym_io[3] 12

set_io mux_sel[0] 23
set_io mux_sel[1] 27
set_io mux_sel[2] 26

set_io mux_oe_n 25
set_io pcm_load 4
set_io rmpx 10
set_io pmpx 11

# YM3016

set_io dac_clk 3
set_io dac_sh1 34
set_io dac_sh2 32
set_io dac_so 9

# SPDIF

set_io spdif_out 45

# MIDI

set_io midi_rx 48

# SPI
set_io spi_io[0] 14
set_io spi_io[1] 17
set_io spi_io[2] 18
set_io spi_io[3] 19

set_io -nowarn spi_clk 15
set_io -nowarn spi_flash_cs_n 16
set_io -nowarn spi_ram_cs_n 6

# USB
set_io -nowarn usb_dp 42
set_io -nowarn usb_dn 38
set_io -nowarn usb_pu 37

# UART
set_io -nowarn uart_rx 47
set_io -nowarn uart_tx 44

# Clock
set_io -nowarn clk_in 35

# Button (bitsy)
set_io -nowarn btn 2

# Button (PCB)
set_io -pullup yes -pullup_resistor 3P3K btn_a 28
set_io -pullup yes -pullup_resistor 3P3K btn_b 31
 
# Leds
set_io -nowarn rgb[0] 39
set_io -nowarn rgb[1] 40
set_io -nowarn rgb[2] 41

# Both an IO + LED on 24?
#set_io led 25

# YM2610

set_io ym_clk 46
set_io ym_shift_load 43
set_io ym_shift_out 36

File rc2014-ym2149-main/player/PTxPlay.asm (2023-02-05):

;Universal PT2 and PT3 player for ZX Spectrum and MSX
;(c)2004-2007 S.V.Bulba <vorobey@mail.khstu.ru>
;http://bulba.untergrund.net (http://bulba.at.kz)

;Release number
Release EQU "1"

;Conditional assembly
;1) Version of ROUT (ZX or MSX standards)
ZX=0
MSX=0
RC=1
;2) Current position counter at (START+11)
CurPosCounter=0
;3) Allow channels allocation bits at (START+10)
ACBBAC=0
;4) Allow loop checking and disabling
LoopChecker=0
;5) Insert official identificator
Id=1

;Features
;--------
;-Can be compiled at any address (i.e. no need rounding ORG
; address).
;-Variables (VARS) can be located at any address (not only after
;code block).
;-INIT subprogram checks PT3-module version and rightly
; generates both note and volume tables outside of code block
; (in VARS).
;-Two portamento (spc. command 3xxx) algorithms (depending of
; PT3 module version).
;-New 1.XX and 2.XX special command behaviour (only for PT v3.7
; and higher).
;-Any Tempo value are accepted (including Tempo=1 and Tempo=2).
;-Fully compatible with Ay_Emul PT3 and PT2 players codes.
;-See also notes at the end of this source code.

;Limitations
;-----------
;-Can run in RAM only (self-modified code is used).
;-PT2 position list must be end by #FF marker only.

;Warning!!! PLAY subprogram can crash if no module are loaded
;into RAM or INIT subprogram was not called before.

;Call MUTE or INIT one more time to mute sound after stopping
;playing

	ORG #C000
	;ORG #100
	; ld hl, startupstr
  ; call print
;Test codes (commented)
	;LD A,2 ;PT2,ABC,Looped
	LD A, 0
	LD (START+10),A
	CALL START
	; ld hl, startupstr
	; call print
;	EI
;_LP	HALT
_LP	CALL START+5
	call pause

	; XOR A
	; IN A,(#FE)
	; CPL
	; AND 15
	JR _LP
	ld hl, endstr
	call print
	JR START+8

TonA	EQU 0
TonB	EQU 2
TonC	EQU 4
Noise	EQU 6
Mixer	EQU 7
AmplA	EQU 8
AmplB	EQU 9
AmplC	EQU 10
Env	EQU 11
EnvTp	EQU 13

;Entry and other points
;START initialize playing of module at MDLADDR
;START+3 initialization with module address in HL
;START+5 play one quark
;START+8 mute
;START+10 setup and status flags
;START+11 current position value (byte) (optional)

START
	LD HL,MDLADDR
	JR INIT
	JP PLAY
	JR MUTE
SETUP	DB 0 ;set bit0, if you want to play without looping
	     ;(optional);
	     ;set bit1 for PT2 and reset for PT3 before
	     ;calling INIT;
	     ;bits2-3: %00-ABC, %01 ACB, %10 BAC (optional);
	     ;bits4-6 are not used
	     ;bit7 is set each time, when loop point is passed
	     ;(optional)
	IF CurPosCounter
CurPos	DB 0 ;for visualization only (i.e. no need for playing)
	ENDIF

;Identifier
	IF Id
	DB "=Uni PT2 and PT3 Player r.",Release,"="
	ENDIF

	IF LoopChecker
CHECKLP	LD HL,SETUP
	SET 7,(HL)
	BIT 0,(HL)
	RET Z
	POP HL
	LD HL,DelyCnt
	INC (HL)
	LD HL,ChanA+CHP.NtSkCn
	INC (HL)
	ENDIF

MUTE	XOR A
	LD H,A
	LD L,A
	LD (AYREGS+AmplA),A
	LD (AYREGS+AmplB),HL
	JP ROUT

INIT
;HL - AddressOfModule
	LD A,(START+10)
	AND 2
	JR NZ,INITPT2

	CALL SETMDAD
	PUSH HL
	LD DE,100
	ADD HL,DE
	LD A,(HL)
	LD (Delay),A
	PUSH HL
	POP IX
	ADD HL,DE
	LD (CrPsPtr),HL
	LD E,(IX+102-100)
	INC HL

	IF CurPosCounter
	LD A,L
	LD (PosSub+1),A
	ENDIF

	ADD HL,DE
	LD (LPosPtr),HL
	POP DE
	LD L,(IX+103-100)
	LD H,(IX+104-100)
	ADD HL,DE
	LD (PatsPtr),HL
	LD HL,169
	ADD HL,DE
	LD (OrnPtrs),HL
	LD HL,105
	ADD HL,DE
	LD (SamPtrs),HL
	LD A,(IX+13-100) ;EXTRACT VERSION NUMBER
	SUB #30
	JR C,L20
	CP 10
	JR C,L21
L20	LD A,6
L21	LD (Version),A
	PUSH AF ;VolTable version
	CP 4
	LD A,(IX+99-100) ;TONE TABLE NUMBER
	RLA
	AND 7
	PUSH AF ;NoteTable number
	LD HL,(e_-SamCnv-2)*256+#18
	LD (SamCnv),HL
	LD A,#BA
	LD (OrnCP),A
	LD (SamCP),A
	LD A,#7B
	LD (OrnLD),A
	LD (SamLD),A
	LD A,#87
	LD (SamClc2),A
	LD BC,PT3PD
	LD HL,0
	LD DE,PT3EMPTYORN
	JR INITCOMMON

INITPT2	LD A,(HL)
	LD (Delay),A
	PUSH HL
	PUSH HL
	PUSH HL
	INC HL
	INC HL
	LD A,(HL)
	INC HL
	LD (SamPtrs),HL
	LD E,(HL)
	INC HL
	LD D,(HL)
	POP HL
	AND A
	SBC HL,DE
	CALL SETMDAD
	POP HL
	LD DE,67
	ADD HL,DE
	LD (OrnPtrs),HL
	LD E,32
	ADD HL,DE
	LD C,(HL)
	INC HL
	LD B,(HL)
	LD E,30
	ADD HL,DE
	LD (CrPsPtr),HL
	LD E,A
	INC HL

	IF CurPosCounter
	LD A,L
	LD (PosSub+1),A
	ENDIF

	ADD HL,DE
	LD (LPosPtr),HL
	POP HL
	ADD HL,BC
	LD (PatsPtr),HL
	LD A,5
	LD (Version),A
	PUSH AF
	LD A,2
	PUSH AF
	LD HL,#51CB
	LD (SamCnv),HL
	LD A,#BB
	LD (OrnCP),A
	LD (SamCP),A
	LD A,#7A
	LD (OrnLD),A
	LD (SamLD),A
	LD A,#80
	LD (SamClc2),A
	LD BC,PT2PD
	LD HL,#8687
	LD DE,PT2EMPTYORN

INITCOMMON

	LD (PTDECOD+1),BC
	LD (PsCalc),HL
	PUSH DE

;note table data depacker
;(c) Ivan Roshin
	LD DE,T_PACK
	LD BC,T1_+(2*49)-1
TP_0	LD A,(DE)
	INC DE
	CP 15*2
	JR NC,TP_1
	LD H,A
	LD A,(DE)
	LD L,A
	INC DE
	JR TP_2
TP_1	PUSH DE
	LD D,0
	LD E,A
	ADD HL,DE
	ADD HL,DE
	POP DE
TP_2	LD A,H
	LD (BC),A
	DEC BC
	LD A,L
	LD (BC),A
	DEC BC
	SUB #F8*2
	JR NZ,TP_0

	IF LoopChecker
	LD HL,SETUP
	RES 7,(HL)

	IF CurPosCounter
	INC HL
	LD (HL),A
	ENDIF

	ELSE

	IF CurPosCounter
	LD (CurPos),A
	ENDIF

	ENDIF

	LD HL,VARS
	LD (HL),A
	LD DE,VARS+1
	LD BC,VAR0END-VARS-1
	LDIR
	LD (AdInPtA),HL ;ptr to zero
	INC A
	LD (DelyCnt),A
	LD HL,#F001 ;H - CHP.Volume, L - CHP.NtSkCn
	LD (ChanA+CHP.NtSkCn),HL
	LD (ChanB+CHP.NtSkCn),HL
	LD (ChanC+CHP.NtSkCn),HL
	POP HL
	LD (ChanA+CHP.OrnPtr),HL
	LD (ChanB+CHP.OrnPtr),HL
	LD (ChanC+CHP.OrnPtr),HL

	POP AF

;NoteTableCreator (c) Ivan Roshin
;A - NoteTableNumber*2+VersionForNoteTable
;(xx1b - 3.xx..3.4r, xx0b - 3.4x..3.6x..VTII1.0)

	LD HL,NT_DATA
	PUSH DE
	LD D,B
	ADD A,A
	LD E,A
	ADD HL,DE
	LD E,(HL)
	INC HL
	SRL E
	SBC A,A
	AND #A7 ;#00 (NOP) or #A7 (AND A)
	LD (L3),A
	EX DE,HL
	POP BC ;BC=T1_
	ADD HL,BC

	LD A,(DE)
	ADD A,T_
	LD C,A
	ADC A,T_/256
	SUB C
	LD B,A
	PUSH BC
	LD DE,NT_
	PUSH DE

	LD B,12
L1	PUSH BC
	LD C,(HL)
	INC HL
	PUSH HL
	LD B,(HL)

	PUSH DE
	EX DE,HL
	LD DE,23
	LD IXH,8

L2	SRL B
	RR C
L3	DB #19	;AND A or NOP
	LD A,C
	ADC A,D	;=ADC 0
	LD (HL),A
	INC HL
	LD A,B
	ADC A,D
	LD (HL),A
	ADD HL,DE
	DEC IXH
	JR NZ,L2

	POP DE
	INC DE
	INC DE
	POP HL
	INC HL
	POP BC
	DJNZ L1

	POP HL
	POP DE

	LD A,E
	CP TCOLD_1
	JR NZ,CORR_1
	LD A,#FD
	LD (NT_+#2E),A

CORR_1	LD A,(DE)
	AND A
	JR Z,TC_EXIT
	RRA
	PUSH AF
	ADD A,A
	LD C,A
	ADD HL,BC
	POP AF
	JR NC,CORR_2
	DEC (HL)
	DEC (HL)
CORR_2	INC (HL)
	AND A
	SBC HL,BC
	INC DE
	JR CORR_1

TC_EXIT

	POP AF

;VolTableCreator (c) Ivan Roshin
;A - VersionForVolumeTable (0..4 - 3.xx..3.4x;
			   ;5.. - 2.x,3.5x..3.6x..VTII1.0)

	CP 5
	LD HL,#11
	LD D,H
	LD E,H
	LD A,#17
	JR NC,M1
	DEC L
	LD E,L
	XOR A
M1      LD (M2),A

	LD IX,VT_+16

	LD C,#F
INITV2  PUSH HL

	ADD HL,DE
	EX DE,HL
	SBC HL,HL

	LD B,#10
INITV1  LD A,L
M2      DB #7D
	LD A,H
	ADC A,0
	LD (IX),A
	INC IX
	ADD HL,DE
	DJNZ INITV1

	POP HL
	LD A,E
	CP #77
	JR NZ,M3
	INC E
M3      DEC C
	JR NZ,INITV2

	JP ROUT

SETMDAD	LD (MODADDR),HL
	LD (MDADDR1),HL
	LD (MDADDR2),HL
	RET

PTDECOD JP #C3C3

;PT2 pattern decoder
PD2_SAM	CALL SETSAM
	JR PD2_LOOP

PD2_EOff LD (IX-12+CHP.Env_En),A
	JR PD2_LOOP

PD2_ENV	LD (IX-12+CHP.Env_En),16
	LD (AYREGS+EnvTp),A
	LD A,(BC)
	INC BC
	LD L,A
	LD A,(BC)
	INC BC
	LD H,A
	LD (EnvBase),HL
	JR PD2_LOOP
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
